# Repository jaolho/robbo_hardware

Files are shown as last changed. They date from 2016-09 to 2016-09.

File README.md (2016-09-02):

# CLONE THE REPOSITORY BY CLICKING THE CLONE BUTTON IN THE UPPER RIGHT SIDE OF THE PAGE - THE ONE WITH A DOWN ARROW. #

# README #

This README would normally document whatever steps are necessary to get your application up and running.

### What is this repository for? ###

* Quick summary
* Version
* [Learn Markdown](https://bitbucket.org/tutorials/markdowndemo)

### How do I get set up? ###

* Summary of set up
* Configuration
* Dependencies
* Database configuration
* How to run tests
* Deployment instructions

### Contribution guidelines ###

* Writing tests
* Code review
* Other guidelines

### Who do I talk to? ###

* Repo owner or admin
* Other community or team contact

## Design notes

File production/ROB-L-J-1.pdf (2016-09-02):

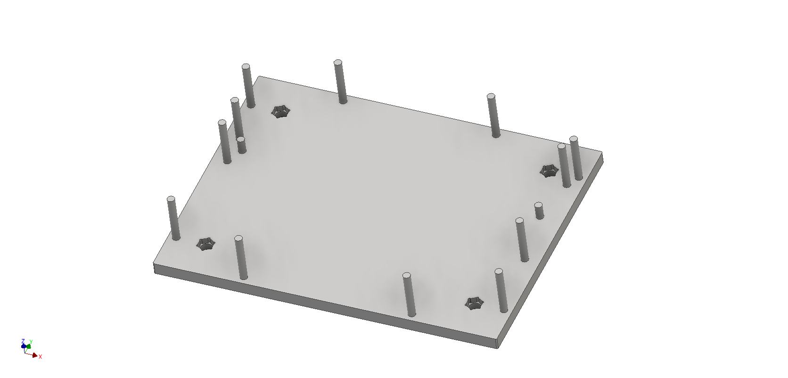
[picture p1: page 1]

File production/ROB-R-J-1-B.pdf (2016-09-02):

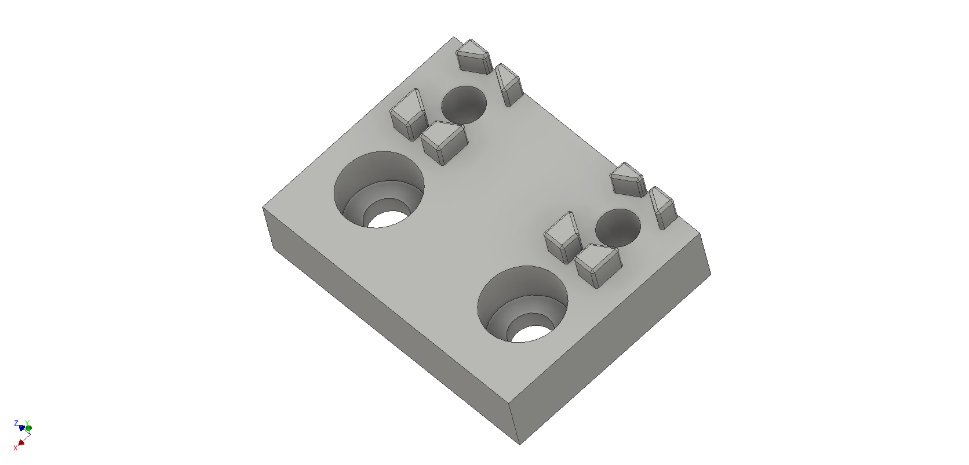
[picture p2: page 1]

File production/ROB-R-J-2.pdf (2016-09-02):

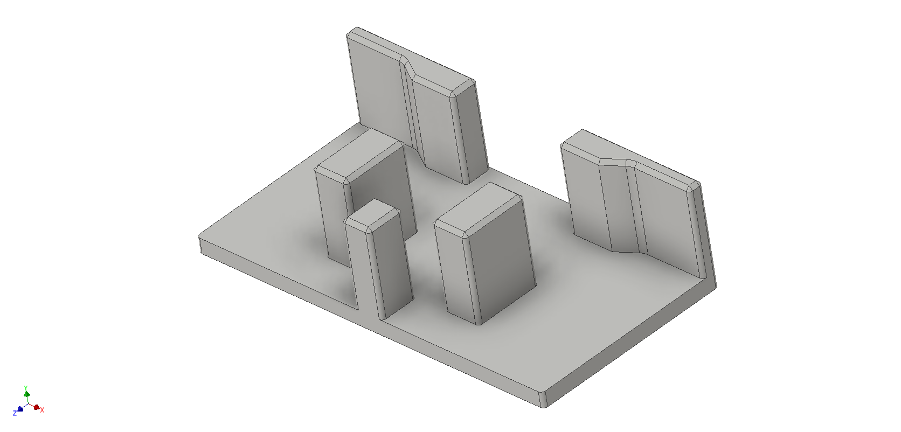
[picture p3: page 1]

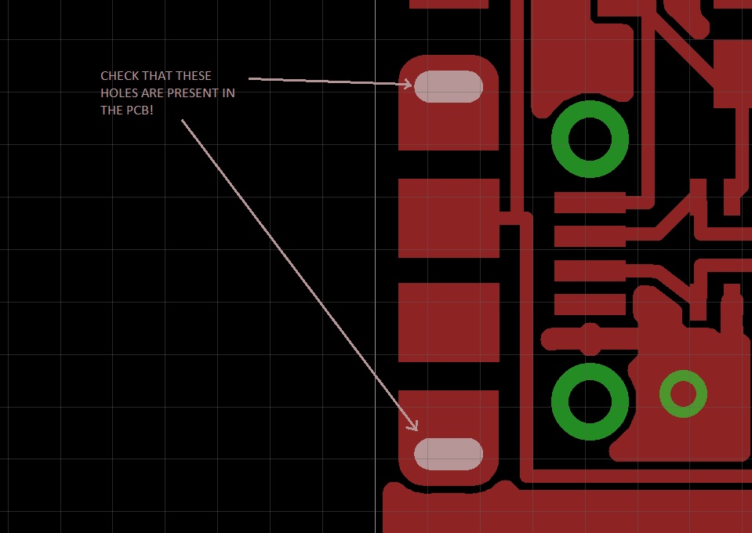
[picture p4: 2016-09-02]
lab/eagle/gerber/USB ADDITIONAL HOLES.jpg

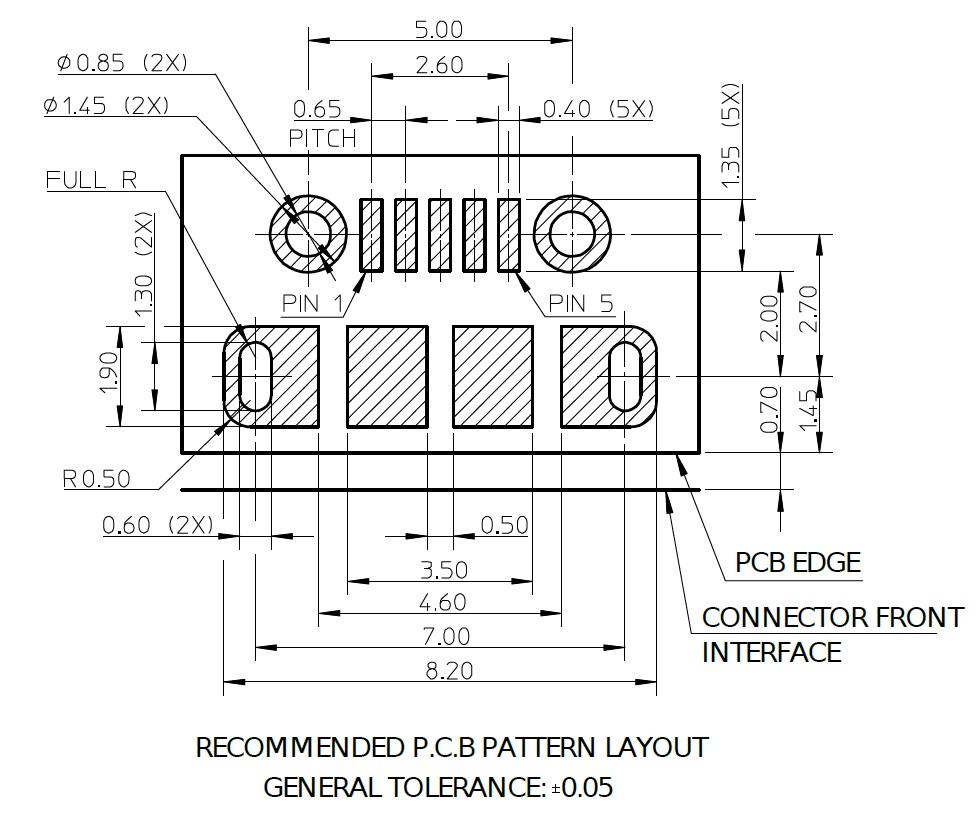
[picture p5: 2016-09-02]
lab/eagle/gerber/USB CONNECTOR HOLE DIMENSIONS.jpg

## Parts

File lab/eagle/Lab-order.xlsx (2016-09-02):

Quantity | Value | Package | Order code | Manufacturer | Manuf. Code | Availability | Price (from) | Description | tot
6 | KSC921J | TACT_SWITCH_4_PIN | 2435155 | C & K COMPONENTS | KSC921J LFS | 807 | 0.288 | C & K COMPONENTS - KSC921J LFS - TACTILE SWITCH, SPST, 0.05A, 32VDC, SMD | 2.2464
1 | 330nF | C0805 | 1833878 | AVX | 08053C334KAT2A | 70485 | 0.131 | AVX - 08053C334KAT2A - CAP, MLCC, X7R, 330NF, 25V, 0805 | 0.1703
10 | 100nF | C0805 | 499687 | AVX | 08055C104KAT2A | 223180 | 0.0086 | AVX - 08055C104KAT2A - CAP, MLCC, X7R, 100NF, 50V, 0805 | 0.1118
1 | 10nF | C0805 | 1759246 | MULTICOMP | MC0805B103K500CT | 109879 | 0.0052 | MULTICOMP - MC0805B103K500CT - CAP, MLCC, X7R, 10NF, 50V, 0805 | 0.00676
2 | 4.7uF | C0805 | 2497057 | WALSIN | 0805X475K250CT | 149027 | 0.0311 | WALSIN - 0805X475K250CT - CAPACITOR, MLCC, X5R, 4.7UF, 25V, 0805 | 0.08086
2 | 22pF | C0805 | 1362555 | YAGEO (PHYCOMP) | CC0805JRNPO9BN220 | 14207 | 0.0038 | YAGEO (PHYCOMP) - CC0805JRNPO9BN220 - CAP, MLCC, C0G/NP0, 22PF, 50V, 0805 | 0.00988
1 | 470nF | C0805 | 1759175 | MULTICOMP | MC0805F474Z250CT | 165234 | 0.0112 | MULTICOMP - MC0805F474Z250CT - CAP, MLCC, Y5V, 470NF, 25V, 0805 | 0.01456
2 | MBR0520 | SOD123 | 1467521 | FAIRCHILD SEMICONDUCTOR | MBR0520L | 9244 | 0.0385 | FAIRCHILD SEMICONDUCTOR - MBR0520L - DIODE, SCHOTTKY, 0.5A, 20V, SMD | 0.1001
4 | 5.1V | SOD-323 | 1431203 | ON SEMICONDUCTOR | MM3Z5V1T1G | 38122 | 0.0196 | ON SEMICONDUCTOR - MM3Z5V1T1G - DIODE, ZENER, 5.1V, 0.2W | 0.10192
1 | 500 mA | PT1206 | 1345942 | TE CONNECTIVITY / RAYCHEM | NANOSMDC050F/13.2-2 | 2740 | 0.123 | TE CONNECTIVITY / RAYCHEM - NANOSMDC050F/13.2-2 - POLYSWITCH, SMD, 1206, 0.5A | 0.1599
1 | FT232RL | SSOP28 | 1146032 | FTDI | FT232RL-REEL | -6 | 1.61 | FTDI - FT232RL-REEL - IC, USB TO UART, SMD, 28SSOP | 2.093
1 | 74HC164D | SO14 | 1085337 | NXP | 74HC164D | 4608 | 0.062 | NXP - 74HC164D - IC, 8BIT SHIFT REGISTER, 14SOIC | 0.0806
1 | ATMEGA328AU/TQFP | TQFP32-08 | 1715486 | ATMEL | ATMEGA328P-AU | 1330 | 1.21 | ATMEL - ATMEGA328P-AU - MCU, 8BIT, ATMEGA, 20MHZ, TQFP-32 | 1.573
1 | 600ohm/100Mhz | R0603 | 1635706 | WURTH ELEKTRONIK | 742792651 | 28900 | 0.0734 | WURTH ELEKTRONIK - 742792651 - FERRITE, BEAD, 0603, 0.2OHM, 1A | 0.09542
3 | KPC-3216SGC (GREEN) | LED3216_PAC | 1318254 | KINGBRIGHT | KPC-3216SGC | 2739 | 0.0877 | KINGBRIGHT - KPC-3216SGC - LED, 1.6MM X 2MM, GREEN, 12MCD, 568NM | 0.34203
1 | KPC-3216YC (YELLOW) | LED3216_PAC | 1318264 | KINGBRIGHT | KPC-3216YC | 210 | 0.0891 | KINGBRIGHT - KPC-3216YC - LED, SMD, CLR LENS, YELLOW | 0.11583
10 | KPC-3216EC (RED) | LED3216_PAC | 1318250 | KINGBRIGHT | KPC-3216EC | 4925 | 0.0862 | KINGBRIGHT - KPC-3216EC - LED, SMD, CLR LENS, RED | 1.1206
1 | ABM-707-RC | ABM-707-RC | 1736563 | PRO SIGNAL | ABM-707-RC | 10790 | 0.494 | PRO SIGNAL - ABM-707-RC - MICROPHONE, OMNI, PCB MOUNT | 0.6422
2 | TSM-108-02-L-SV | FE08 | 1593463 | MULTICOMP | 2212S-08SG-85 | 30147 | 0.126 | MULTICOMP - 2212S-08SG-85 - SOCKET, PCB, 1 ROW, 8WAY | 0.3276
1 | TSM-106-02-L-SV | FE06 | 1593462 | MULTICOMP | 2212S-06SG-85 | 3284 | 0.0914 | MULTICOMP - 2212S-06SG-85 - SOCKET, PCB, 1 ROW, 6WAY | 0.11882
1 | TSM-110-02-L-SV | FE10 | 1593464 | MULTICOMP | 2212S-10SG-85 | 22134 | 0.206 | MULTICOMP - 2212S-10SG-85 - SOCKET, PCB, 1 ROW, 10WAY | 0.2678
1 | SFH3410SMD | SFH3410 | 1226438 | OSRAM | SFH3410-Z | 872 | 0.377 | OSRAM - SFH3410-Z - PHOTOTRANSISTOR, EYE-RESPONSE | 0.4901
1 | LFXTAL003237 | SM49 | 9713808 | IQD FREQUENCY PRODUCTS | LFXTAL003237 | 20932 | 0.135 | IQD FREQUENCY PRODUCTS - LFXTAL003237 - CRYSTAL, SMD, 16MHZ | 0.1755
1 | BC850 | MY_SOT23 | 1081241 | NXP | BC850C,215 | 67732 | 0.0241 | NXP - BC850C,215 - TRANSISTOR, NPN, 45V, SOT-23 | 0.03133
1 | 0R | R0805 | 9333681 | MULTICOMP | MC01W08050R | 906385 | 0.0014 | MULTICOMP - MC01W08050R - RESISTOR, THICK FILM, 0R, 0.1W | 0.00182
23 | 1k | R0805 | 1652936 | VISHAY DRALORIC | CRCW08051K00FKTA | 1325 | 0.018 | VISHAY DRALORIC - CRCW08051K00FKTA - RES, THICK FILM, 1K, 1%, 0.125W, 0805 | 0.5382
9 | 10k | R0805 | 9237755 | YAGEO (PHYCOMP) | RC0805FR-0710KL | 367165 | 0.0042 | YAGEO (PHYCOMP) - RC0805FR-0710KL - RES, THICK FILM, 10K, 1%, 0.125W, 0805 | 0.04914
1 | 2k2 | R0805 | 9237534 | YAGEO (PHYCOMP) | RC0805FR-072K2L. | 16874 | 0.0043 | YAGEO (PHYCOMP) - RC0805FR-072K2L. - RES, THICK FILM, 2K2, 1%, 0.125W, 0805 | 0.00559
2 | 100k | R0805 | 9237879 | YAGEO (PHYCOMP) | RC0805FR-07100KL | 2127 | 0.0043 | YAGEO (PHYCOMP) - RC0805FR-07100KL - RES, THICK FILM, 100K, 1%, 0.125W, 0805 | 0.01118
1 | PTA4543 | PTA4543 | 1688415 | BOURNS | PTA4543-2015DPB103 | 679 | 0.476 | BOURNS - PTA4543-2015DPB103 - POTENTIOMETER, SLIDE, 10K, 45MM | 0.6188
1 | MCABT-458-RC | SMD_SPK_PAC | 2433031 | MULTICOMP | MCABT-458-RC | 248 | 0.892 | MULTICOMP - MCABT-458-RC - SOUNDER, 75DB, 1-25V, SMD | 1.1596
1 | USB-CON-5PIN | USB-MICRO-MOLEX-105017-0001_V2 | 2293836 | MOLEX | 105017-0001 | 5630 | 0.265 | MOLEX - 105017-0001 - MICRO USB, 2.0 TYPE B, RECEPTACLE, SMT | 0.3445
1 | PRTR5V0U4Y | SOT363 | 1757870 | NXP | PRTR5V0U4Y,125 | 14639 | 0.0512 | NXP - PRTR5V0U4Y,125 - DIODE ESD, PROTECT, SOT-363 | 0.06656
1 | UA78M05CDCY | SOT230P700X180-4N | 2296030 | TEXAS INSTRUMENTS | UA78M05CDCY | 2313 | 0.141 | TEXAS INSTRUMENTS - UA78M05CDCY - V REG, 0.5A, 5V, 5%, 4SOT223 | 0.1833
1 | SRF3216A | SRF3216A | 2493828 | BOURNS | SRF3216A-900Y | 969 | 0.31 | BOURNS - SRF3216A-900Y - FILTER, COMMON MODE, 90R, 0.4A, SMD | 0.403
3 | FC68125 | FC68125 | 2309468 | CLIFF ELECTRONIC COMPONENTS | FC68125 | 1011 | 0.49 | CLIFF ELECTRONIC COMPONENTS - FC68125 - CONNECTOR, PHONO, 3.5MM, JACK, 4POLE | 1.911
1 | 200 mA | PT1206 | 1345939 | TE CONNECTIVITY / RAYCHEM | NANOSMDC020F-2 | 439 | 0.1096 | TE CONNECTIVITY / RAYCHEM - NANOSMDC020F-2 - POLYSWITCH, SMD, 1206, 0.2A | 0.14248
2 | 74FST3257 | SO16 | 2464460 | ON SEMICONDUCTOR | 74FST3257DR2G | -2 | 0.166 | ON SEMICONDUCTOR - 74FST3257DR2G - MUX/DEMUX, QUAD, 2:1, SOIC-16 | 0.4316
3 | 220R | M0805 | 2447606 | MULTICOMP | MCWR08X2200FTL | 61112 | 0.0051 | MULTICOMP - MCWR08X2200FTL - RES, THICK FILM, 220R, 1%, 0.125W, 0805 | 0.01989
1 | 219-02 | CTS-219-02 | 1524005 | MULTICOMP | MCEMR-02-T | 43377 | 0.236 | MULTICOMP - MCEMR-02-T - SWITCH, 2 WAY, SPST, FLUSH | 0.3068
 |  |  |  |  |  |  |  |  | 16.66977

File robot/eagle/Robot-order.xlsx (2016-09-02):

Quantity | Value | Package | Order code | Manufacturer | Manuf. Code | Availability | Price (from) | Description
1 | UA78M05CDCY | SOT230P700X180-4N | 2296030 | TEXAS INSTRUMENTS | UA78M05CDCY | 2313 | 0.141 | TEXAS INSTRUMENTS - UA78M05CDCY - V REG, 0.5A, 5V, 5%, 4SOT223
1 | RN42-I/RM | RN42 | 2143310 | MICROCHIP | RN42-I/RM | 4010 | 11.5 | MICROCHIP - RN42-I/RM - MODULE, BLUETOOTH CLASS 2, W/ ANT
3 | KSC921J | TACT_SWITCH_4_PIN | 2435155 | C & K COMPONENTS | KSC921J LFS | 807 | 0.288 | C & K COMPONENTS - KSC921J LFS - TACTILE SWITCH, SPST, 0.05A, 32VDC, SMD
1 | 330nF | C0805 | 1833878 | AVX | 08053C334KAT2A | 70485 | 0.131 | AVX - 08053C334KAT2A - CAP, MLCC, X7R, 330NF, 25V, 0805
18 | 100nF | C0805 | 499687 | AVX | 08055C104KAT2A | 223180 | 0.0086 | AVX - 08055C104KAT2A - CAP, MLCC, X7R, 100NF, 50V, 0805
1 | 10nF | C0805 | 1759246 | MULTICOMP | MC0805B103K500CT | 109879 | 0.0052 | MULTICOMP - MC0805B103K500CT - CAP, MLCC, X7R, 10NF, 50V, 0805
2 | 4.7uF | C0805 | 1735529 | MURATA | GRM21BR61E475KA12L | 12464 | 0.0181 | MURATA - GRM21BR61E475KA12L - CAP, MLCC, X5R, 4.7UF, 25V, 0805
3 | 47uF | C1210 | 1907527 | MURATA | GRM32EC81C476KE15L | 3213 | 0.136 | MURATA - GRM32EC81C476KE15L - CAP, MLCC, X6S, 47UF, 16V, 1210
2 | 22pF | C0805 | 1362555 | YAGEO (PHYCOMP) | CC0805JRNPO9BN220 | 14207 | 0.0038 | YAGEO (PHYCOMP) - CC0805JRNPO9BN220 - CAP, MLCC, C0G/NP0, 22PF, 50V, 0805
2 | MBR0520 | SOD123 | 1467521 | FAIRCHILD SEMICONDUCTOR | MBR0520L | 9259 | 0.0385 | FAIRCHILD SEMICONDUCTOR - MBR0520L - DIODE, SCHOTTKY, 0.5A, 20V, SMD
1 | BAV99 | SOT23 | 1621837 | MULTICOMP | BAV99 | 120250 | 0.0096 | MULTICOMP - BAV99 - DIODE, DUAL, SMALL SIG, 75V, SOT-23-3
1 | 500 mA | PT1206 | 1345942 | TE CONNECTIVITY / RAYCHEM | NANOSMDC050F/13.2-2 | 2740 | 0.123 | TE CONNECTIVITY / RAYCHEM - NANOSMDC050F/13.2-2 - POLYSWITCH, SMD, 1206, 0.5A
1 | FT232RL | SSOP28 | 1146032 | FTDI | FT232RL-REEL | -6 | 1.61 | FTDI - FT232RL-REEL - IC, USB TO UART, SMD, 28SSOP
1 | ATMEGA328AU/TQFP | TQFP32-08 | 1715486 | ATMEL | ATMEGA328P-AU | 1330 | 1.21 | ATMEL - ATMEGA328P-AU - MCU, 8BIT, ATMEGA, 20MHZ, TQFP-32
4 | 1X01 PIN | 1X01 | 2356152 | WURTH ELEKTRONIK | 61300111121 | 155 | 0.0337 | WURTH ELEKTRONIK - 61300111121 - HEADER, 2.54MM, PIN, THT, VERTICAL, 1WAY
1 | 600ohm/100Mhz | R0603 | 1635706 | WURTH ELEKTRONIK | 742792651 | 28900 | 0.0734 | WURTH ELEKTRONIK - 742792651 - FERRITE, BEAD, 0603, 0.2OHM, 1A
3 | KPC-3216SGC | LED3216_PAC | 1318254 | KINGBRIGHT | KPC-3216SGC | 2739 | 0.0877 | KINGBRIGHT - KPC-3216SGC - LED, 1.6MM X 2MM, GREEN, 12MCD, 568NM
2 | APT3216QBC/D (BLUE) | LED3216_PAC | 2217976 | KINGBRIGHT | KP-3216QBC-D | 4477 | 0.115 | KINGBRIGHT - KP-3216QBC-D - LED, SMD, 1206 BLUE
2 | KPC-3216YC | LED3216_PAC | 1318264 | KINGBRIGHT | KPC-3216YC | 210 | 0.0891 | KINGBRIGHT - KPC-3216YC - LED, SMD, CLR LENS, YELLOW
2 | KPC-3216SGC (GREEN) | LED3216_PAC | 1318254 | KINGBRIGHT | KPC-3216SGC | 2739 | 0.0877 | KINGBRIGHT - KPC-3216SGC - LED, 1.6MM X 2MM, GREEN, 12MCD, 568NM
2 | KPC-3216EC (RED) | LED3216_PAC | 1318250 | KINGBRIGHT | KPC-3216EC | 4925 | 0.0862 | KINGBRIGHT - KPC-3216EC - LED, SMD, CLR LENS, RED
1 | LV8548 | LV8548 | 2217011 | ON SEMICONDUCTOR | LV8548MC-AH | 949 | 0.639 | ON SEMICONDUCTOR - LV8548MC-AH - DRIVER, MOTOR, 2CH, 12V, BIDIR, 10SOIC
1 | 16MHz | SM49 | 9713808 | IQD FREQUENCY PRODUCTS | LFXTAL003237 | 20942 | 0.135 | IQD FREQUENCY PRODUCTS - LFXTAL003237 - CRYSTAL, SMD, 16MHZ
1 | 0R | R0805 | 9333681 | MULTICOMP | MC01W08050R | 906385 | 0.0014 | MULTICOMP - MC01W08050R - RESISTOR, THICK FILM, 0R, 0.1W
16 | 1k | R0805 | 1652936 | VISHAY DRALORIC | CRCW08051K00FKTA | 1325 | 0.018 | VISHAY DRALORIC - CRCW08051K00FKTA - RES, THICK FILM, 1K, 1%, 0.125W, 0805
8 | 10k | R0805 | 9237755 | YAGEO (PHYCOMP) | RC0805FR-0710KL | 377165 | 0.0042 | YAGEO (PHYCOMP) - RC0805FR-0710KL - RES, THICK FILM, 10K, 1%, 0.125W, 0805
1 | 22k | R0805 | 1099809 | WELWYN | WCR0805-22KFI | 53934 | 0.0059 | WELWYN - WCR0805-22KFI - RES, THICK FILM, 22K, 1%, 0.125W, 0805
1 | 39k | R0805 | 1100325 | WELWYN | WCR0805-39KFI | 32215 | 0.0063 | WELWYN - WCR0805-39KFI - RES, THICK FILM, 39K, 1%, 0.1W, 0805
1 | PRTR5V0U4Y | SOT363 | 1757870 | NXP | PRTR5V0U4Y,125 | 14639 | 0.0512 | NXP - PRTR5V0U4Y,125 - DIODE ESD, PROTECT, SOT-363
1 | USB-CON-5PIN | USB-MICRO-MOLEX-105017-0001_V2 | 2293836 | MOLEX | 105017-0001 | 5630 | 0.265 | MOLEX - 105017-0001 - MICRO USB, 2.0 TYPE B, RECEPTACLE, SMT
1 | SRF3216A | SRF3216A | 2493828 | BOURNS | SRF3216A-900Y | 969 | 0.31 | BOURNS - SRF3216A-900Y - FILTER, COMMON MODE, 90R, 0.4A, SMD
2 | KTIR07SMD | KTIR07 | 2079967 | KINGBRIGHT | KTIR0721DS | -6 | 0.221 | KINGBRIGHT - KTIR0721DS - PHOTO INTERRUPTER
1 | SN74HCT14PWR | SOP65P640X120-14N | 1287559 | TEXAS INSTRUMENTS | SN74HCT14PWR | 1990 | 0.0782 | TEXAS INSTRUMENTS - SN74HCT14PWR - IC, INVERTER, SMD, TSSOP14, 7V
1 | CD4072BM | SOIC127P600X175-14N | 1753434 | TEXAS INSTRUMENTS | CD4072BM | 150 | 0.0954 | TEXAS INSTRUMENTS - CD4072BM - LOGIC, DUAL 4INPUT OR GATE, 14SOIC
2 | TC33-TRIMPOT | TC33-TRIMPOT | 1689867 | BOURNS | TC33X-2-503E | 1603 | 0.0709 | BOURNS - TC33X-2-503E - TRIMMER, POT, 50K, 25%, 1TURN, SMD
1 | N-MOSFET | SOT23 | 9845011 | FAIRCHILD SEMICONDUCTOR | FDV301N | 16626 | 0.0258 | FAIRCHILD SEMICONDUCTOR - FDV301N - N CHANNEL MOSFET, 220MA, 25V, SOT23
15 | 220R | R0805 | 2447606 | MULTICOMP | MCWR08X2200FTL | 61112 | 0.0051 | MULTICOMP - MCWR08X2200FTL - RES, THICK FILM, 220R, 1%, 0.125W, 0805
2 | 750k | R0805 | 9333550 | MULTICOMP | MC01W08051750K | 1679 | 0.0032 | MULTICOMP - MC01W08051750K - RES, THICK FILM, 750K, 1%, 0.1W, 0805
1 | 330k | R0805 | 1652983 | VISHAY DRALORIC | CRCW0805330KFKEA | 5406 | 0.008 | VISHAY DRALORIC - CRCW0805330KFKEA - RES, THICK FILM, 330K, 1%, 0.125W, 0805
1 | 4M7 | R0805 | 2352630 | VISHAY DRALORIC | RCV08054M70FKEA | 655 | 0.0155 | VISHAY DRALORIC - RCV08054M70FKEA - RES, THICK FILM, 4M7, 1%, 0.125W, 0805
1 | 4060BM | SO16 | 1741260 | TEXAS INSTRUMENTS | CD4060BM | 3715 | 0.0976 | TEXAS INSTRUMENTS - CD4060BM - LOGIC, BIN COUNTER/DIV/OSC, 16SOIC
1 | UA78M33CDCY | SOT230P700X180-4N | 2296031 | TEXAS INSTRUMENTS | UA78M33CDCY | 1846 | 0.125 | TEXAS INSTRUMENTS - UA78M33CDCY - V REG, 2VDO, 0.5A, 3.3V, 4SOT223
1 | BATTERY_9V | BATTERY_PAC | 1888429 | KEYSTONE | 967 | -10 | 0.472 | KEYSTONE - 967 - BATTERY CONTACT, 9V, VERTICAL PCB SNAP-ON
2 | 1uF | C0805 | 2496944 | WALSIN | 0805B104K500CT | 2004666 | 0.0041 | WALSIN - 0805B104K500CT - CAPACITOR, MLCC, X7R, 0.1UF, 50V, 0805
1 | LTC2955CTS8-2 | 8TSOT23 | 2097940 | LINEAR TECHNOLOGY | LTC2955CTS8-2#TRMPBF | 521 | 1.67 | LINEAR TECHNOLOGY - LTC2955CTS8-2#TRMPBF - CONTROLLER, PUSHBUTTON ON/OFF, 8TSOT23
4 | SD1206 | SD1206 | 2400198 | AVX | SD1206S040S2R0 | 2356 | 0.0816 | AVX - SD1206S040S2R0 - DIODE, SCHOTTKY, 2A, 40V, SOD-123
2 | 200 mA | PT1206 | 1345939 | TE CONNECTIVITY / RAYCHEM | NANOSMDC020F-2 | 439 | 0.1096 | TE CONNECTIVITY / RAYCHEM - NANOSMDC020F-2 - POLYSWITCH, SMD, 1206, 0.2A
1 | 2x11 HEADER | 2X11 | 1593495 | MULTICOMP | 2214S-22SG-85 | 1244 | 0.273 | MULTICOMP - 2214S-22SG-85 - SOCKET, PCB, 2 ROW, VERT, 22WAY
2 | IRLML5203PBF (3A) | SOT23 | 9103511 | INTERNATIONAL RECTIFIER | IRLML5203PBF | 32283 | 0.0765 | INTERNATIONAL RECTIFIER - IRLML5203PBF - MOSFET,P CH,-30V,-3A,SOT23
1 | 90k9 | R0805 | 2141897 | MULTICOMP | MC01W0805190K9 | 2455 | 0.0044 | MULTICOMP - MC01W0805190K9 - RES, THICK FILM, 90K9, 1%, 0.1W, 0805
4 | 100k | R0805 | 9237879 | YAGEO (PHYCOMP) | RC0805FR-07100KL | 2127 | 0.0043 | YAGEO (PHYCOMP) - RC0805FR-07100KL - RES, THICK FILM, 100K, 1%, 0.125W, 0805
1 | 120k | R0805 | 9237887 | YAGEO (PHYCOMP) | RC0805FR-07120KL | 8001 | 0.0018 | YAGEO (PHYCOMP) - RC0805FR-07120KL - RES, THICK FILM, 120K, 1%, 0.125W, 0805
1 | 1M | R0805 | 1853267 | VISHAY DALE | CRCW08051M00FKTB | 3248 | 0.006 | VISHAY DALE - CRCW08051M00FKTB - RES, THICK FILM, 1M, 1%, 0.125W, 0805
3 | MAX803SC | SC70-3L | 2318552 | ON SEMICONDUCTOR | MAX803SQ293T1G | 2885 | 0.108 | ON SEMICONDUCTOR - MAX803SQ293T1G - RESET, 2.93VTH, 0.14-0.46S, ACT LW,3SC70
1 | SWS006 | SMS-006 | 9472045 | MULTICOMP | MCDM(R)-06-T | 5005 | 1.13 | MULTICOMP - MCDM(R)-06-T - SWITCH, DIL, SMD, 6WAY
5 | ESDA5V3L | SOT23 | 1749266 | STMICROELECTRONICS | ESDA5V3L | 6822 | 0.0705 | STMICROELECTRONICS - ESDA5V3L - TRANSIL ARRAY UNI DUAL ESD SOT-23

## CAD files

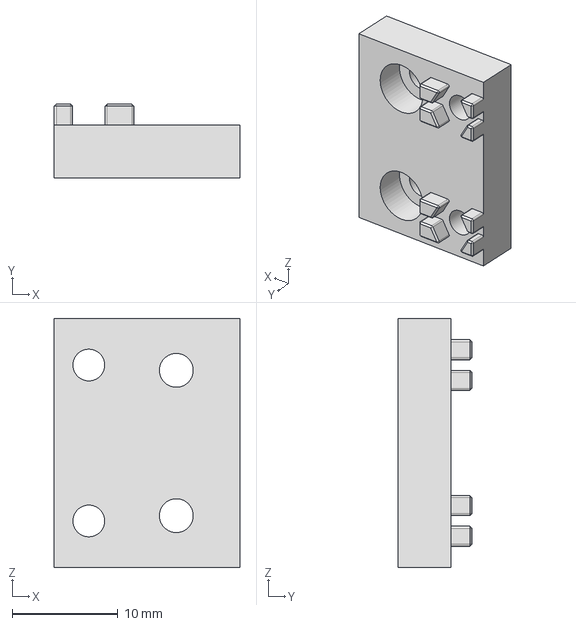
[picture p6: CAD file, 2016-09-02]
production/ROB-R-J-1.stp
17.5 x 7.00 x 23.5 mm

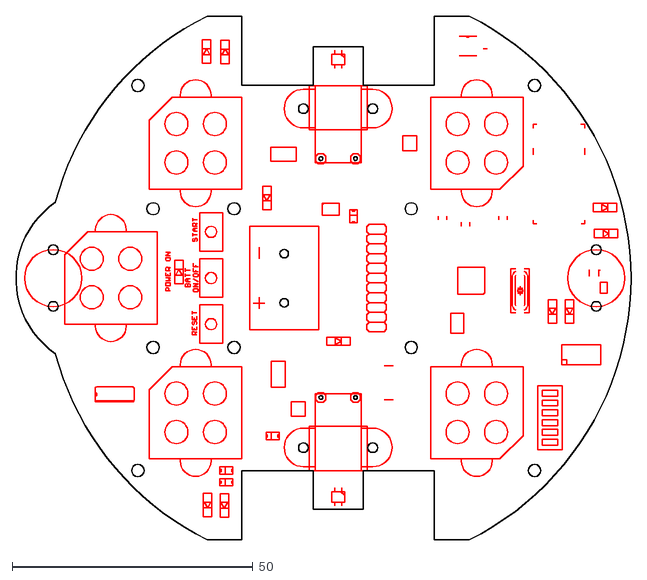
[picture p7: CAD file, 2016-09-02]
robot/plastics/Robot reference.dxf
127.7 x 108.7

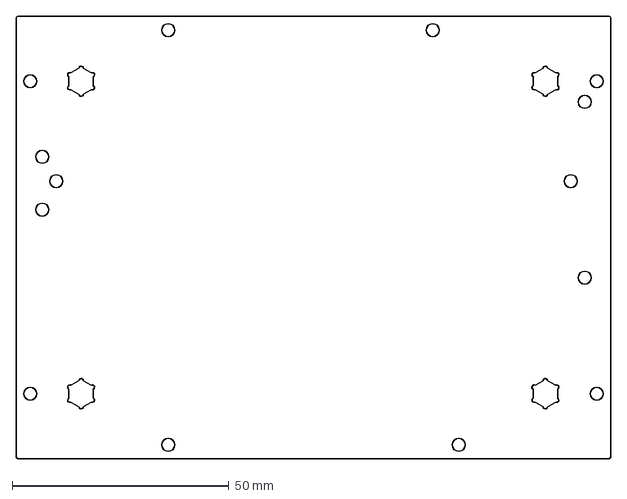
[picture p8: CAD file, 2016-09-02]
production/ROB-L-J-1-FACE1.dxf
137.0 x 102.0 mm

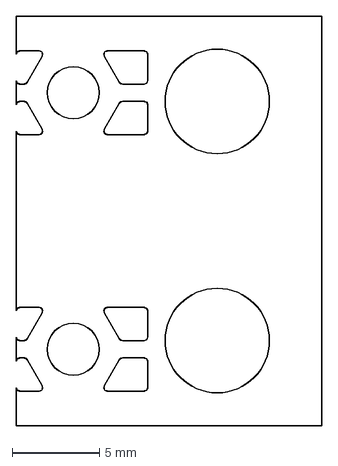
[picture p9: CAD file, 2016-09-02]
production/ROB-R-J-1-B-FACE1.dxf
17.5 x 23.5 mm

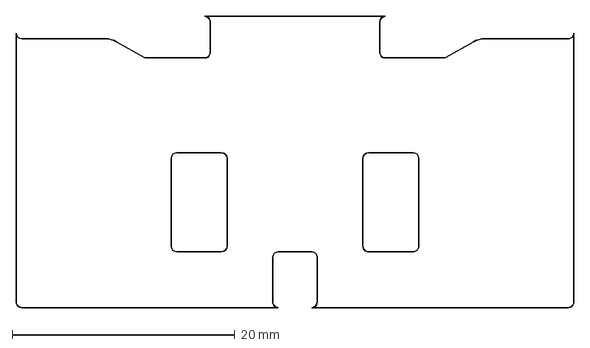
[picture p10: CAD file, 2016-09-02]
production/ROB-R-J-2-FACE1.dxf
50.0 x 26.1 mm

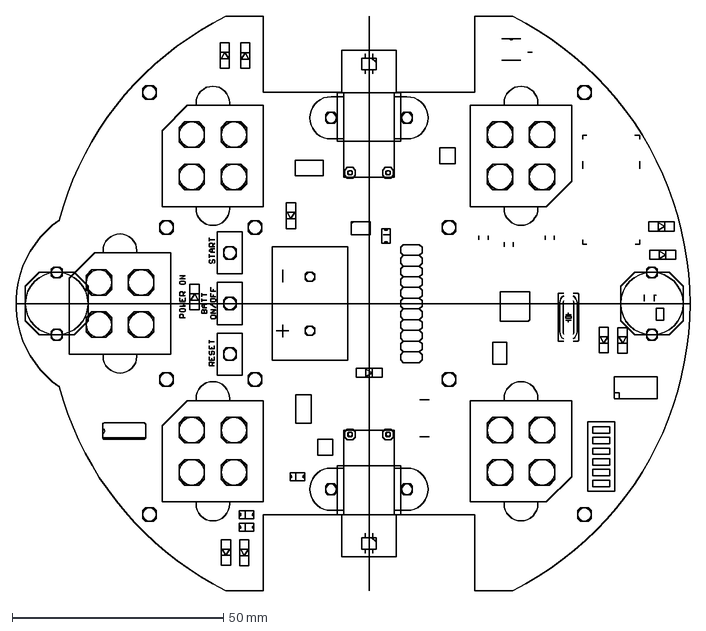
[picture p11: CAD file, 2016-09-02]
production/ROB-R-FACE1.dxf
159.7 x 136.0 mm

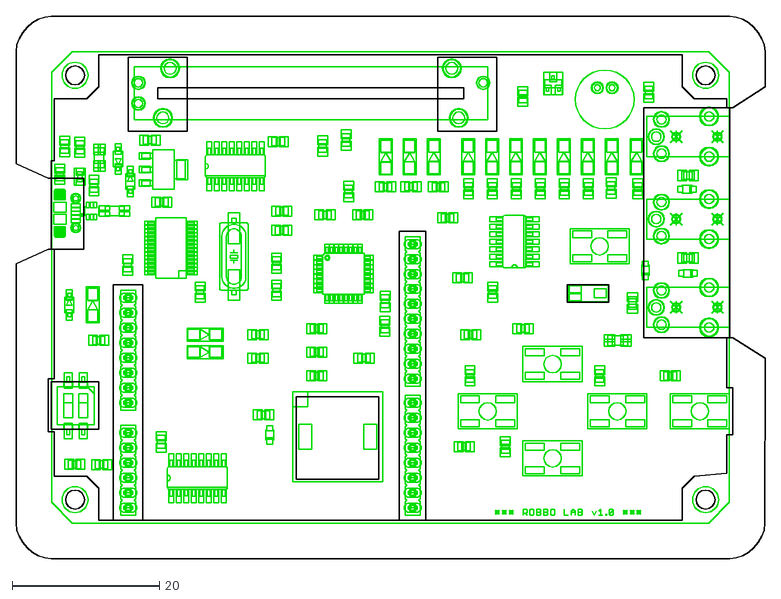
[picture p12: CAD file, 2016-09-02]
production/Lab-plastics.dxf
101.6 x 73.6

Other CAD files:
production/OldVersions/ROB-L-J-1-B.0001.ipt
production/OldVersions/ROB-L-J-1-B.0002.ipt
production/OldVersions/ROB-L-J-1.0002.ipt
production/OldVersions/ROB-L-J-1.0004.ipt
production/OldVersions/ROB-R-J-1.0004.ipt
production/OldVersions/ROB-R-J-2.0003.ipt
production/ROB-L-J-1.ipt
production/ROB-R-J-1-B.ipt
production/ROB-R-J-1.dwg
production/ROB-R-J-1.ipt
production/ROB-R-J-2.ipt
production/ROB-R-J-3.ipt

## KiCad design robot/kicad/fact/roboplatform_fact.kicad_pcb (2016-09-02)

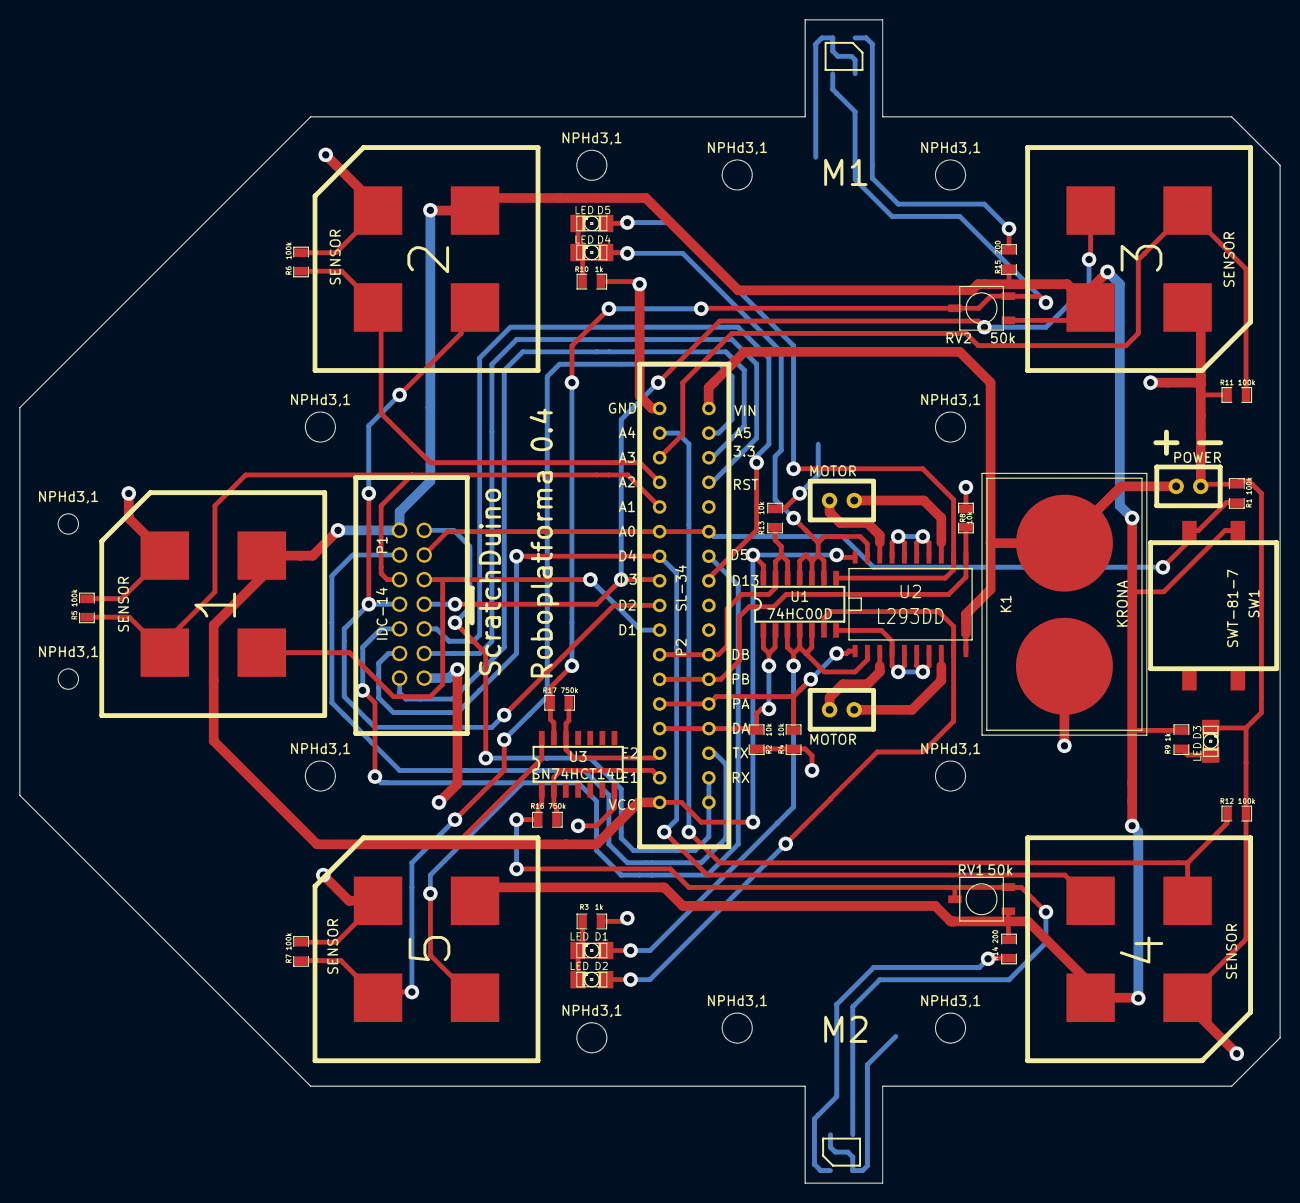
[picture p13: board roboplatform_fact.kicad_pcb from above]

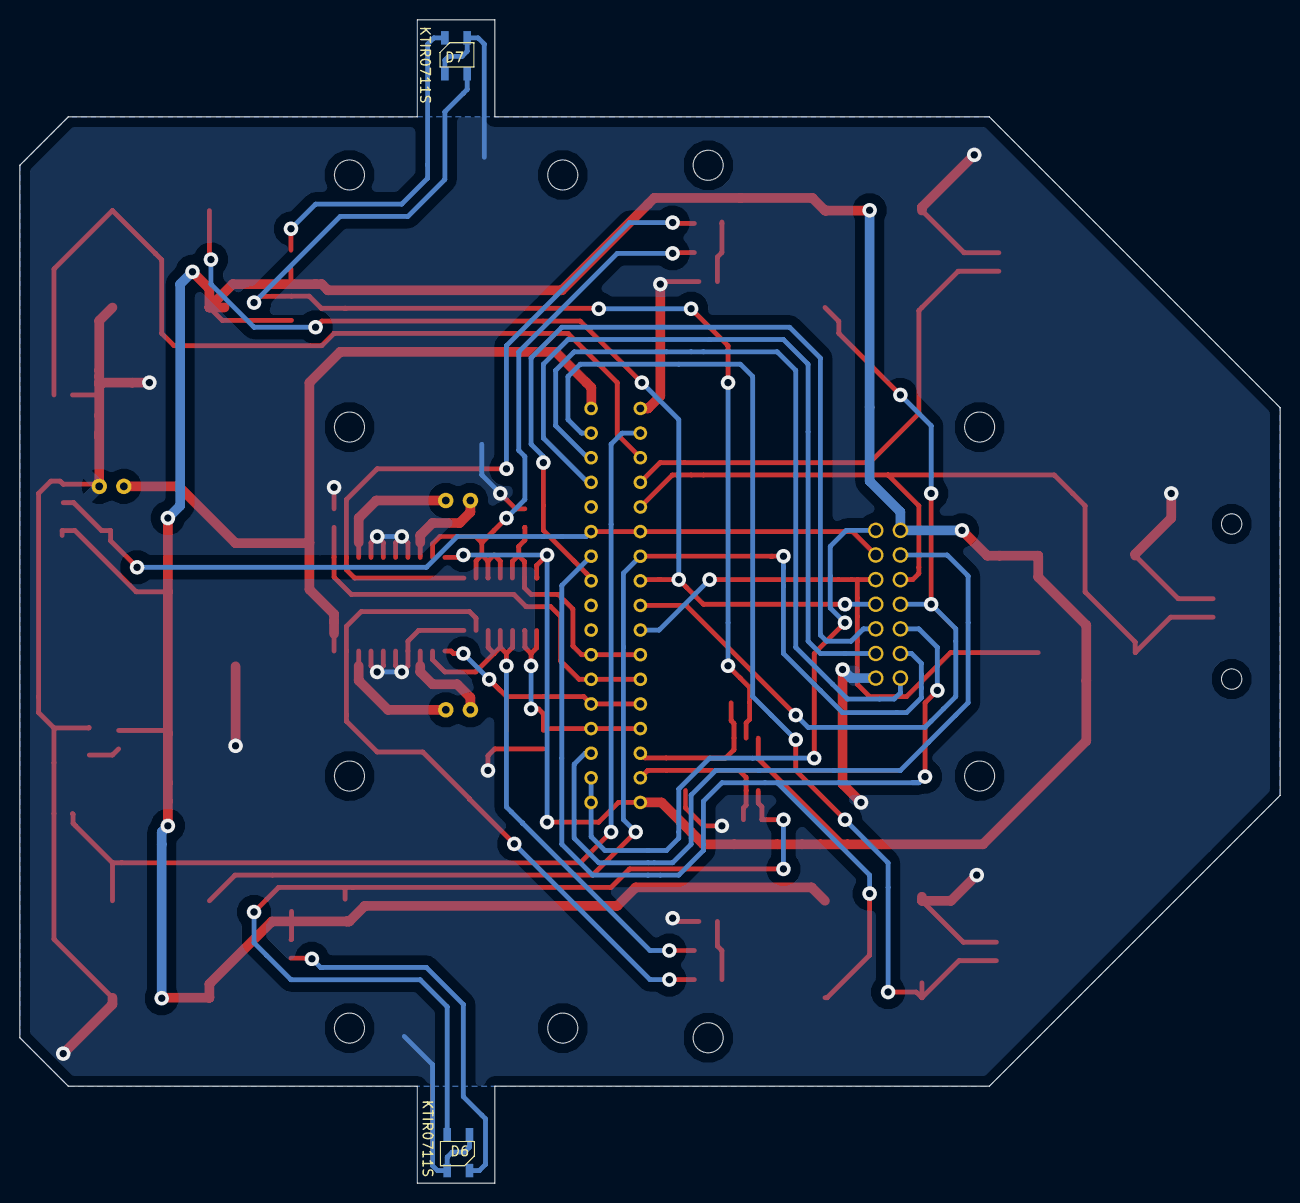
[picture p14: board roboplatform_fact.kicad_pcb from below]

Board: 2 copper layers, 130.0 x 120.0 mm, 53 parts (2 on the bottom side), 40 nets.

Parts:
D1, D2, D3, D4, D5: LED; LED-1206
D6, D7: KTIR0711S
K1: KRONA
NPHd3,1, NPHd3,1#2, NPHd3,1#3, NPHd3,1#4, NPHd3,1#5, NPHd3,1#6, NPHd3,1#7, NPHd3,1#8, NPHd3,1#9, NPHd3,1#10: NPHd3,1
NPHd3,1#11, NPHd3,1#12: NPHd2,1
P1: IDC-14; IDC-14M_SOCKET
P2: SL-34; SL-34_SOCKET
P3, P12: MOTOR
P6, P7, P8, P10, P11: SENSOR; SENSOR_SOCKET
P9: POWER
R1, R5, R6, R7, R11, R12: 100k; SMD0805
R2, R4, R8, R13: 10k; SMD0805
R3, R9, R10: 1k; SMD0805
R14, R15: 200; SMD0805
R16, R17: 750k; SMD0805
RV1, RV2: 50k; 3314G-1-503E
SW1: SWT-81-7
U1: 74HC00D; SOIC-14
U2: L293DD; SO20
U3: SN74HCT14D; SOIC-14

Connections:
A1: P1.10, P2.5, P6.4, R5.1
A2: P2.4, P7.4, R6.1
A3: P2.3, P10.4, R11.1
A4: P2.2, P11.4, R12.1
A5: P2.33, P8.4, R7.1
D1: P1.9, P2.10, P6.3
D2: P1.8, P2.9, P7.3
D3: P1.7, P2.8, P10.3
D4: P1.4, P2.7, P11.3
D5: P1.6, P2.28, P8.3
DIR_A: P2.14, P2.21, R2.1, U1.1, U1.2
DIR_B: P2.11, P2.24, R13.1, U1.12, U1.13
ENC1: P2.16, R16.1, U3.2
ENC2: P2.15, R17.2, U3.12
GND: D3.2, D6.2, D6.4, D7.2, D7.4, K1.2, P1.1, P2.1, P6.1, P7.1, P8.1, P9.2, P10.1, P11.1, R1.2, R2.2, R3.1, R4.1, R5.2, R6.2, R7.2, R8.2, R10.1, R11.2, R12.2, R13.2, U1.7, U2.4, U2.5, U2.6, U2.7, U2.14, U2.15, U2.16, U2.17, U3.7
unnamed: P1.12, P2.20
unnamed: P1.13, P2.18, P2.19
unnamed: P1.3, P2.31
unnamed: P1.2, P2.32
unnamed: P3.2, U2.3
unnamed: P1.11, P2.6, P2.29, R1.1, SW1.1
unnamed: P3.1, U2.8
unnamed: D1.1, U1.3, U1.4, U1.5, U2.2
unnamed: P12.1, U2.13
unnamed: P12.2, U2.18
unnamed: D4.1, U1.9, U1.10, U1.11, U2.19
unnamed: D7.1, R15.2
unnamed: D6.1, R14.2
unnamed: D2.1, U1.6, U2.9
unnamed: P1.5, P2.27
unnamed: D3.1, R9.2
unnamed: D7.3, R17.1, RV2.1, RV2.2, U3.13
unnamed: D6.3, R16.2, RV1.1, RV1.2, U3.1
unnamed: D1.2, D2.2, R3.2
unnamed: D4.2, D5.2, R10.2
unnamed: D5.1, U1.8, U2.12
PWM_A: P2.13, P2.22, R4.2, U2.1
PWM_B: P2.12, P2.23, R8.1, U2.11
VCC: P1.14, P2.17, P6.2, P7.2, P8.2, P10.2, P11.2, R9.1, R14.1, R15.1, RV1.3, RV2.3, SW1.2, U1.14, U2.20, U3.14
V_IN: K1.1, P2.34, P9.1, U2.10

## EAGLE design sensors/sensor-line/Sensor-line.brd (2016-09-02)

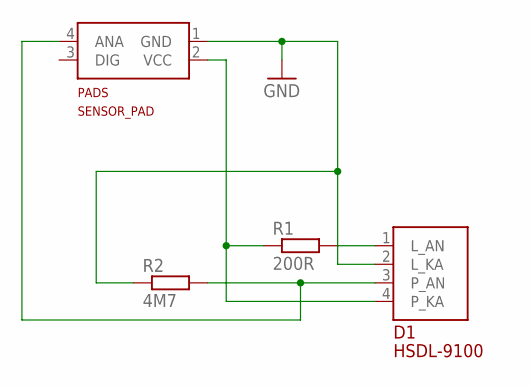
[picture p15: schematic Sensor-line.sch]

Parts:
D1: HSDL-9100; MPN HSDL-9100-021
PADS: SENSOR_PAD
R1: 200R; R1206; MPN ERJ8ENF2000V
R2: 4M7; R0805; MPN ASC0805-4M7FT5

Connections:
GND: D1.2 (L_KA), PADS.1 (GND), R2.1
unnamed: D1.1 (L_AN), R1.2
unnamed: D1.3 (P_AN), PADS.4 (ANA), R2.2
unnamed: D1.4 (P_KA), PADS.2 (VCC), R1.1

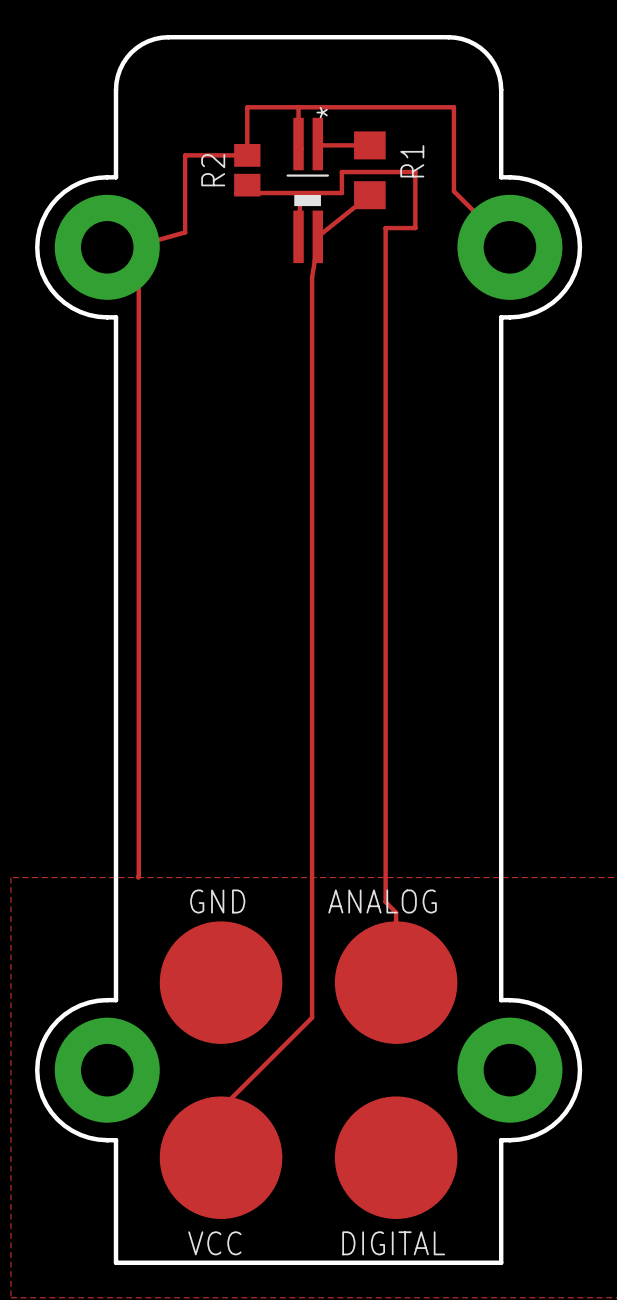
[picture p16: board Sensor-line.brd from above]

Board: 2 copper layers, 31.0 x 70.0 mm, 4 parts (1 on the bottom side), 4 nets.

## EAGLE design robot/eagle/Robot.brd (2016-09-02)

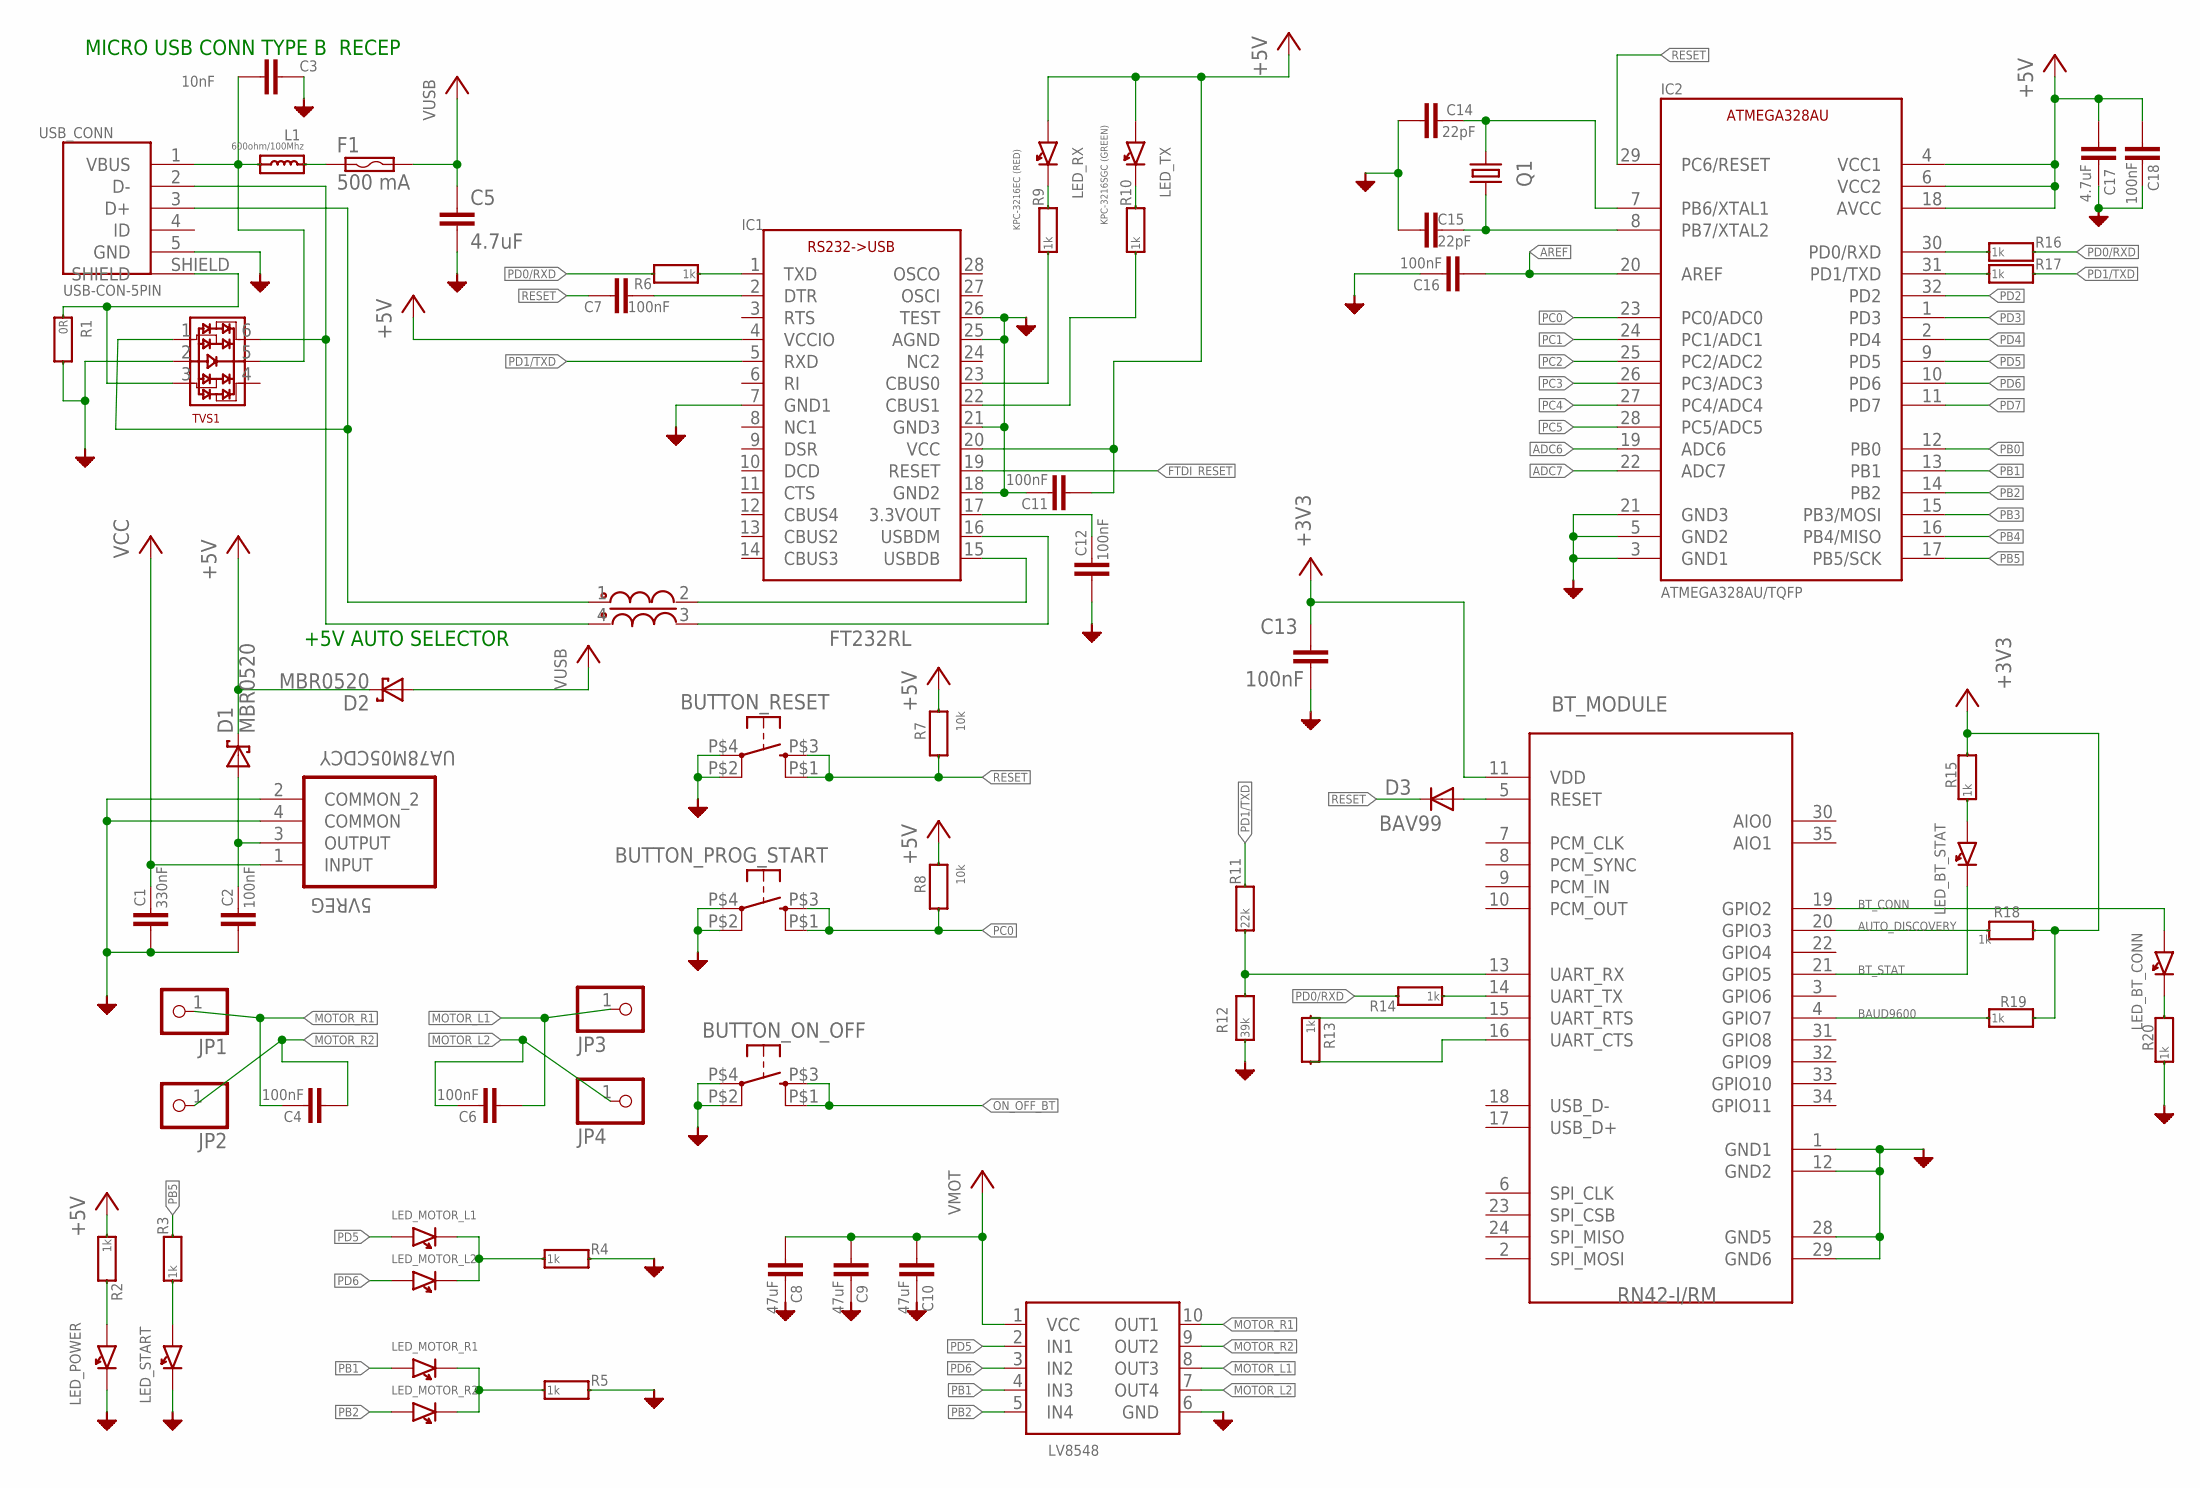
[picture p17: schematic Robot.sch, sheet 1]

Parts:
5VREG: UA78M05CDCY; SOT230P700X180-4N
BT_MODULE: RN42-I/RM; RN42; MPN RN42-I/RM
BUTTON_ON_OFF: KSC921J; TACT_SWITCH_4_PIN; MPN KSC921J LFS
BUTTON_PROG_START: KSC921J; TACT_SWITCH_4_PIN; MPN KSC921J LFS
BUTTON_RESET: KSC921J; TACT_SWITCH_4_PIN; MPN KSC921J LFS
C1: 330nF; C0805; MPN 08053C334KAT2A
C2, C4, C6, C7, C11, C12, C13, C16, C18: 100nF; C0805; MPN 08055C104KAT2A
C3: 10nF; C0805; MPN MC0805B103K500CT
C5, C17: 4.7uF; C0805; MPN GRM21BR61E475KA12L
C8, C9, C10: 47uF; C1210; MPN GRM32EC81C476KE15L
C14, C15: 22pF; C0805; MPN CC0805JRNPO9BN220
D1, D2: MBR0520; SOD123; MPN MBR0520L
D3: BAV99; SOT23; MPN BAV99
F1: 500 mA; PT1206; MPN NANOSMDC050F/13.2-2
IC1: FT232RL; SSOP28; MPN FT232RL-REEL
IC2: ATMEGA328AU/TQFP; TQFP32-08; MPN ATMEGA328P-AU
JP1, JP2, JP3, JP4: 1X01 PIN; 1X01; MPN 61300111121
L1: 600ohm/100Mhz; R0603; MPN 742792651
LED_BT_CONN: KPC-3216SGC; LED3216_PAC; MPN KPC-3216SGC
LED_BT_STAT: KPC-3216SGC; LED3216_PAC; MPN KPC-3216SGC
LED_MOTOR_L1: APT3216QBC/D (BLUE); LED3216_PAC; MOUSER_PART_NO 604-APT3216QBC/D
LED_MOTOR_L2: KPC-3216YC; LED3216_PAC; MPN KPC-3216YC
LED_MOTOR_R1: APT3216QBC/D (BLUE); LED3216_PAC; MOUSER_PART_NO 604-APT3216QBC/D
LED_MOTOR_R2: KPC-3216YC; LED3216_PAC; MPN KPC-3216YC
LED_POWER: KPC-3216SGC (GREEN); LED3216_PAC; MPN KPC-3216SGC
LED_RX: KPC-3216EC (RED); LED3216_PAC; MPN KPC-3216EC
LED_START: KPC-3216SGC; LED3216_PAC; MPN KPC-3216SGC
LED_TX: KPC-3216SGC (GREEN); LED3216_PAC; MPN KPC-3216SGC
MOTOR_CONTROLLER: LV8548; MPN LV8548MC-AH
Q1: 16MHz; SM49; MPN LFXTAL003237
R1: 0R; R0805; MPN MC01W08050R
R2, R3, R4, R5, R6, R9, R10, R13, R14, R15, R16, R17, R18, R19, R20: 1k; R0805; MPN CRCW08051K00FKTA
R7, R8: 10k; R0805; MPN RC0805FR-0710KL
R11: 22k; R0805; MPN WCR0805-22KFI
R12: 39k; R0805; MPN WCR0805-39KFI
TVS1: PRTR5V0U4Y; SOT363; MPN PRTR5V0U4Y,125
USB_CONN: USB-CON-5PIN; USB-MICRO-MOLEX-105017-0001_V2; MPN 105017-0001
USB_FILTER: SRF3216A; MPN SRF3216A-900Y

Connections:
+3V3: BT_MODULE.11 (VDD), C13.1, R15.2, R18.2, R19.2; also elsewhere on the board
+5V: C11.2, C17.2, C18.2, D1.1 (K), D2.1 (K), IC1.4 (VCCIO), IC1.20 (VCC), IC2.4 (VCC1), IC2.6 (VCC2), IC2.18 (AVCC), LED_RX.1, LED_TX.1, R2.1, R7.2, R8.2; also elsewhere on the board
ADC6: IC2.19 (ADC6); also elsewhere on the board
ADC7: IC2.22 (ADC7); also elsewhere on the board
AREF: C16.2, IC2.20 (AREF); also elsewhere on the board
AUTO_DISCOVERY: BT_MODULE.20 (GPIO3), R18.1
BAUD9600: BT_MODULE.4 (GPIO7), R19.1
BT_CONN: BT_MODULE.19 (GPIO2), LED_BT_CONN.1
BT_STAT: BT_MODULE.21 (GPIO5), LED_BT_STAT.2
FTDI_RESET: IC1.19 (RESET); also elsewhere on the board
GND: 5VREG.2 (COMMON_2), 5VREG.4 (COMMON), BT_MODULE.1 (GND1), BT_MODULE.12 (GND2), BT_MODULE.28 (GND5), BT_MODULE.29 (GND6), BUTTON_ON_OFF.P$2 (2), BUTTON_ON_OFF.P$4 (1), BUTTON_PROG_START.P$2 (2), BUTTON_PROG_START.P$4 (1), BUTTON_RESET.P$2 (2), BUTTON_RESET.P$4 (1), C1.2, C2.2, C3.1, C5.2, C8.1, C9.1, C10.1, C11.1, C12.2, C13.2, C14.2, C15.2, C16.1, C17.1, C18.1, IC1.7 (GND1), IC1.18 (GND2), IC1.21 (GND3), IC1.25 (AGND), IC1.26 (TEST), IC2.3 (GND1), IC2.5 (GND2), IC2.21 (GND3), LED_POWER.2, LED_START.2, MOTOR_CONTROLLER.6 (GND), R1.2, R4.2, R5.2, R12.1, R20.1, TVS1.2, USB_CONN.5 (GND); also elsewhere on the board
MOTOR_L1: C6.2, JP3.1, MOTOR_CONTROLLER.8 (OUT3)
MOTOR_L2: C6.1, JP4.1, MOTOR_CONTROLLER.7 (OUT4)
MOTOR_L_ON: LED_MOTOR_L1.2, LED_MOTOR_L2.2, R4.1
MOTOR_R1: C4.1, JP1.1, MOTOR_CONTROLLER.10 (OUT1)
MOTOR_R2: C4.2, JP2.1, MOTOR_CONTROLLER.9 (OUT2)
MOTOR_R_ON: LED_MOTOR_R1.2, LED_MOTOR_R2.2, R5.1
unnamed: BT_MODULE.5 (RESET), D3.1 (A)
unnamed: IC1.1 (TXD), R6.1
unnamed: LED_START.1, R3.1
unnamed: BT_MODULE.14 (UART_TX), R14.1
unnamed: BT_MODULE.15 (UART_RTS), R13.1
unnamed: BT_MODULE.16 (UART_CTS), R13.2
unnamed: IC1.15 (USBDB), USB_FILTER.2
unnamed: LED_BT_STAT.1, R15.1
unnamed: LED_BT_CONN.2, R20.2
unnamed: IC1.16 (USBDM), USB_FILTER.3
unnamed: BT_MODULE.13 (UART_RX), R11.1, R12.2
unnamed: F1.1A (1), F1.1B (1), L1.1
unnamed: 5VREG.3 (OUTPUT), C2.1, D1.2 (A)
unnamed: C12.1, IC1.17 (3.3VOUT)
unnamed: C15.1, IC2.8 (PB7/XTAL2), Q1.2
unnamed: C14.1, IC2.7 (PB6/XTAL1), Q1.1
unnamed: TVS1.1, USB_CONN.3 (D+), USB_FILTER.1
unnamed: TVS1.6, USB_CONN.2 (D-), USB_FILTER.4
unnamed: C7.1, IC1.2 (DTR)
unnamed: C3.2, L1.2, TVS1.5, USB_CONN.1 (VBUS)
unnamed: IC1.23 (CBUS0), R9.1
unnamed: LED_RX.2, R9.2
unnamed: LED_TX.2, R10.2
unnamed: IC1.22 (CBUS1), R10.1
unnamed: LED_POWER.1, R2.2
unnamed: IC2.30 (PD0/RXD), R16.1
unnamed: IC2.31 (PD1/TXD), R17.1
ON_OFF_BT: BUTTON_ON_OFF.P$1 (4), BUTTON_ON_OFF.P$3 (3); also elsewhere on the board
PB0: IC2.12 (PB0); also elsewhere on the board
PB1: IC2.13 (PB1), LED_MOTOR_R1.1, MOTOR_CONTROLLER.4 (IN3); also elsewhere on the board
PB2: IC2.14 (PB2), LED_MOTOR_R2.1, MOTOR_CONTROLLER.5 (IN4)
PB3: IC2.15 (PB3/MOSI); also elsewhere on the board
PB4: IC2.16 (PB4/MISO); also elsewhere on the board
PB5: IC2.17 (PB5/SCK), R3.2; also elsewhere on the board
PC0: BUTTON_PROG_START.P$1 (4), BUTTON_PROG_START.P$3 (3), IC2.23 (PC0/ADC0), R8.1; also elsewhere on the board
PC1: IC2.24 (PC1/ADC1); also elsewhere on the board
PC2: IC2.25 (PC2/ADC2); also elsewhere on the board
PC3: IC2.26 (PC3/ADC3); also elsewhere on the board
PC4: IC2.27 (PC4/ADC4); also elsewhere on the board
PC5: IC2.28 (PC5/ADC5); also elsewhere on the board
PD0/RXD: R6.2, R14.2, R16.2
PD1/TXD: IC1.5 (RXD), R11.2, R17.2
PD2: IC2.32 (PD2); also elsewhere on the board
PD3: IC2.1 (PD3); also elsewhere on the board
PD4: IC2.2 (PD4); also elsewhere on the board
PD5: IC2.9 (PD5), LED_MOTOR_L1.1, MOTOR_CONTROLLER.2 (IN1); also elsewhere on the board
PD6: IC2.10 (PD6), LED_MOTOR_L2.1, MOTOR_CONTROLLER.3 (IN2)
PD7: IC2.11 (PD7); also elsewhere on the board
RESET: BUTTON_RESET.P$1 (4), BUTTON_RESET.P$3 (3), C7.2, D3.3 (C), IC2.29 (PC6/RESET), R7.1; also elsewhere on the board
SHIELD: R1.1, TVS1.3, USB_CONN.SHIELD
USB_VCC: C5.1, D2.2 (A), F1.2A (2), F1.2B (2); also elsewhere on the board
VCC: 5VREG.1 (INPUT), C1.1; also elsewhere on the board
VMOT: C8.2, C9.2, C10.2, MOTOR_CONTROLLER.1 (VCC); also elsewhere on the board

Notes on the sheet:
MICRO USB CONN TYPE B RECEP
+5V AUTO SELECTOR

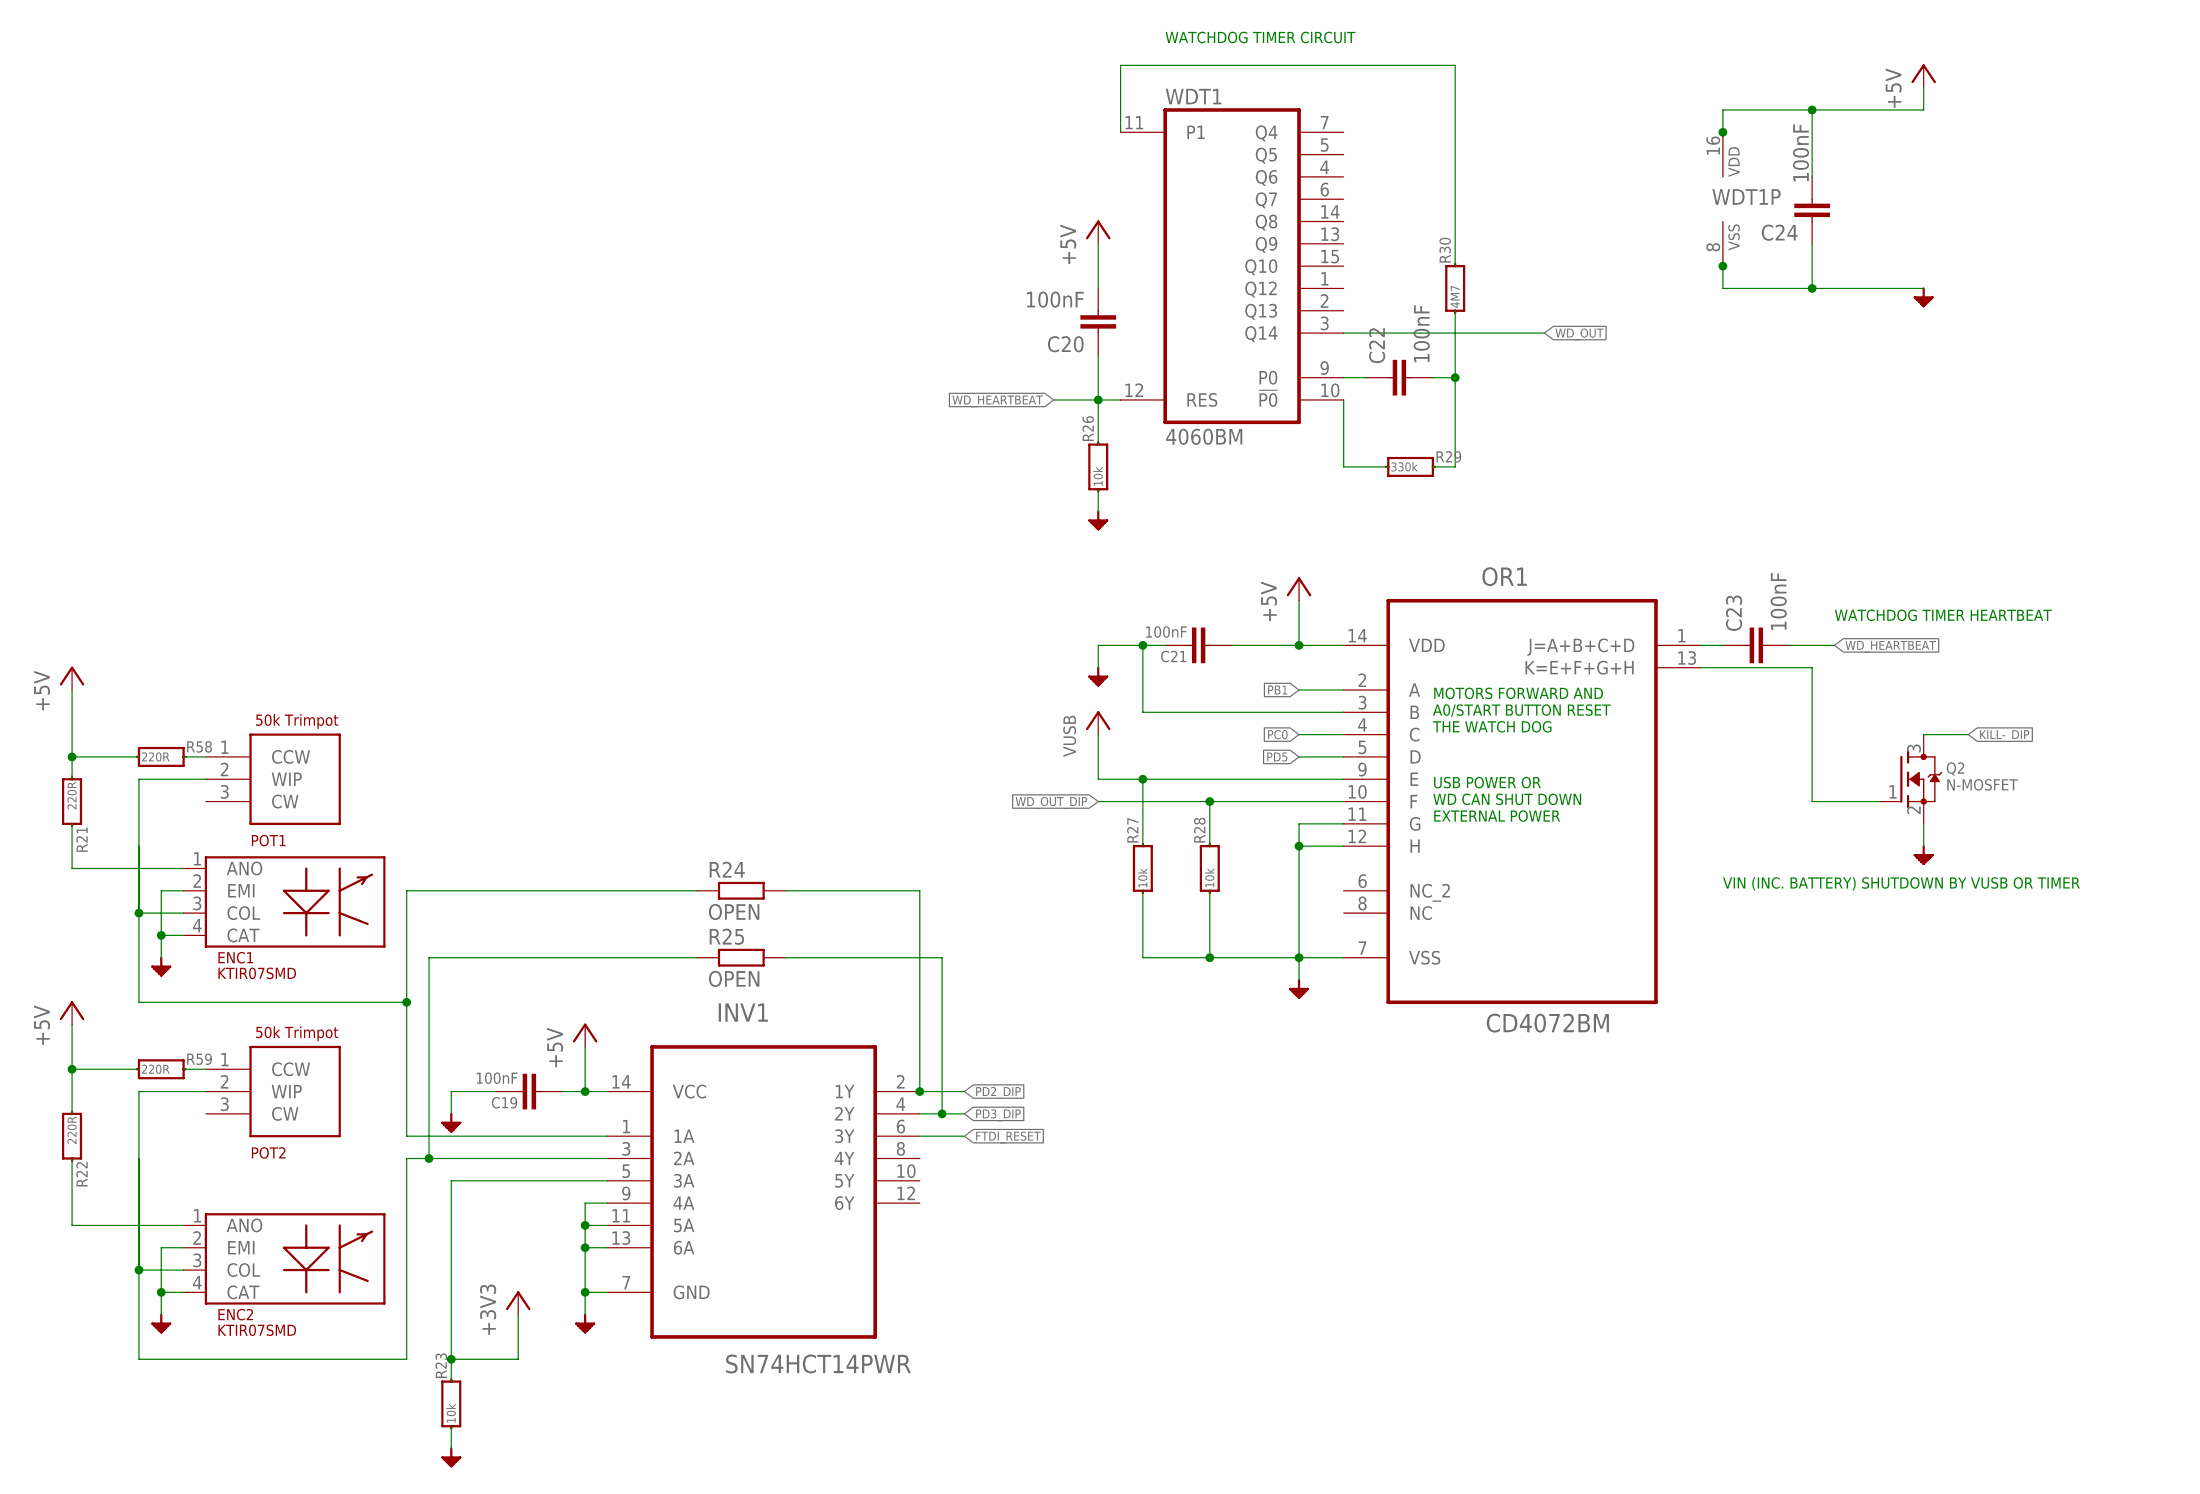
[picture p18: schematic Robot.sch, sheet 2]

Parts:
C19, C20, C21, C22, C23, C24: 100nF; C0805; MPN 08055C104KAT2A
ENC1, ENC2: KTIR07SMD; KTIR07; MPN KTIR0711S
INV1: SN74HCT14PWR; SOP65P640X120-14N; MPN 74HCT14PW,118
OR1: CD4072BM; SOIC127P600X175-14N
POT1, POT2: TC33-TRIMPOT; MPN TC33X-2-503E
Q2: N-MOSFET; SOT23; MPN FDV301N
R21, R22, R58, R59: 220R; R0805; MPN MCWR08X2200FTL
R23, R26, R27, R28: 10k; R0805; MPN RC0805FR-0710KL
R24, R25: OPEN; R0805
R29: 330k; R0805; MPN CRCW0805330KFKEA
R30: 4M7; R0805; MPN RCV08054M70FKEA
WDT1: 4060BM; SO16; MPN CD4060BM

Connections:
+3V3: INV1.5 (3A), R23.2; also elsewhere on the board
+5V: C19.2, C20.2, C21.2, C24.2, INV1.14 (VCC), OR1.14 (VDD), R21.1, R22.1, R58.1, R59.1, WDT1.16 (VDD); also elsewhere on the board
FTDI_RESET: INV1.6 (3Y); also elsewhere on the board
GND: C19.1, C21.1, C24.1, ENC1.2 (EMI), ENC1.4 (CAT), ENC2.2 (EMI), ENC2.4 (CAT), INV1.7 (GND), INV1.9 (4A), INV1.11 (5A), INV1.13 (6A), OR1.3 (B), OR1.7 (VSS), OR1.11 (G), OR1.12 (H), Q2.2 (S), R23.1, R26.1, R27.1, R28.1, WDT1.8 (VSS); also elsewhere on the board
KILL-_DIP: Q2.3 (D); also elsewhere on the board
unnamed: C23.1, OR1.1 (J=A+B+C+D)
unnamed: ENC1.1 (ANO), R21.2
unnamed: ENC2.1 (ANO), R22.2
unnamed: ENC2.3 (COL), INV1.3 (2A), POT2.2 (WIP), R25.1
unnamed: R29.1, WDT1.10 (!P0)
unnamed: ENC1.3 (COL), INV1.1 (1A), POT1.2 (WIP), R24.1
unnamed: C22.1, WDT1.9 (P0)
unnamed: POT2.1 (CCW), R59.2
unnamed: R30.2, WDT1.11 (P1)
unnamed: POT1.1 (CCW), R58.2
unnamed: C22.2, R29.2, R30.1
PB1: OR1.2 (A); also elsewhere on the board
PC0: OR1.4 (C); also elsewhere on the board
PD2_DIP: INV1.2 (1Y), R24.2; also elsewhere on the board
PD3_DIP: INV1.4 (2Y), R25.2; also elsewhere on the board
PD5: OR1.5 (D); also elsewhere on the board
USB/WD_KILL-: OR1.13 (K=E+F+G+H), Q2.1 (G)
USB_VCC: OR1.9 (E), R27.2; also elsewhere on the board
WD_HEARTBEAT: C20.1, C23.2, R26.2, WDT1.12 (RES)
WD_OUT: WDT1.3 (Q14); also elsewhere on the board
WD_OUT_DIP: OR1.10 (F), R28.2; also elsewhere on the board

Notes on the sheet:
WATCHDOG TIMER CIRCUIT
WATCHDOG TIMER HEARTBEAT
VIN (INC. BATTERY) SHUTDOWN BY VUSB OR TIMER
MOTORS FORWARD AND A0/START BUTTON RESET THE WATCH DOG
USB POWER OR WD CAN SHUT DOWN EXTERNAL POWER

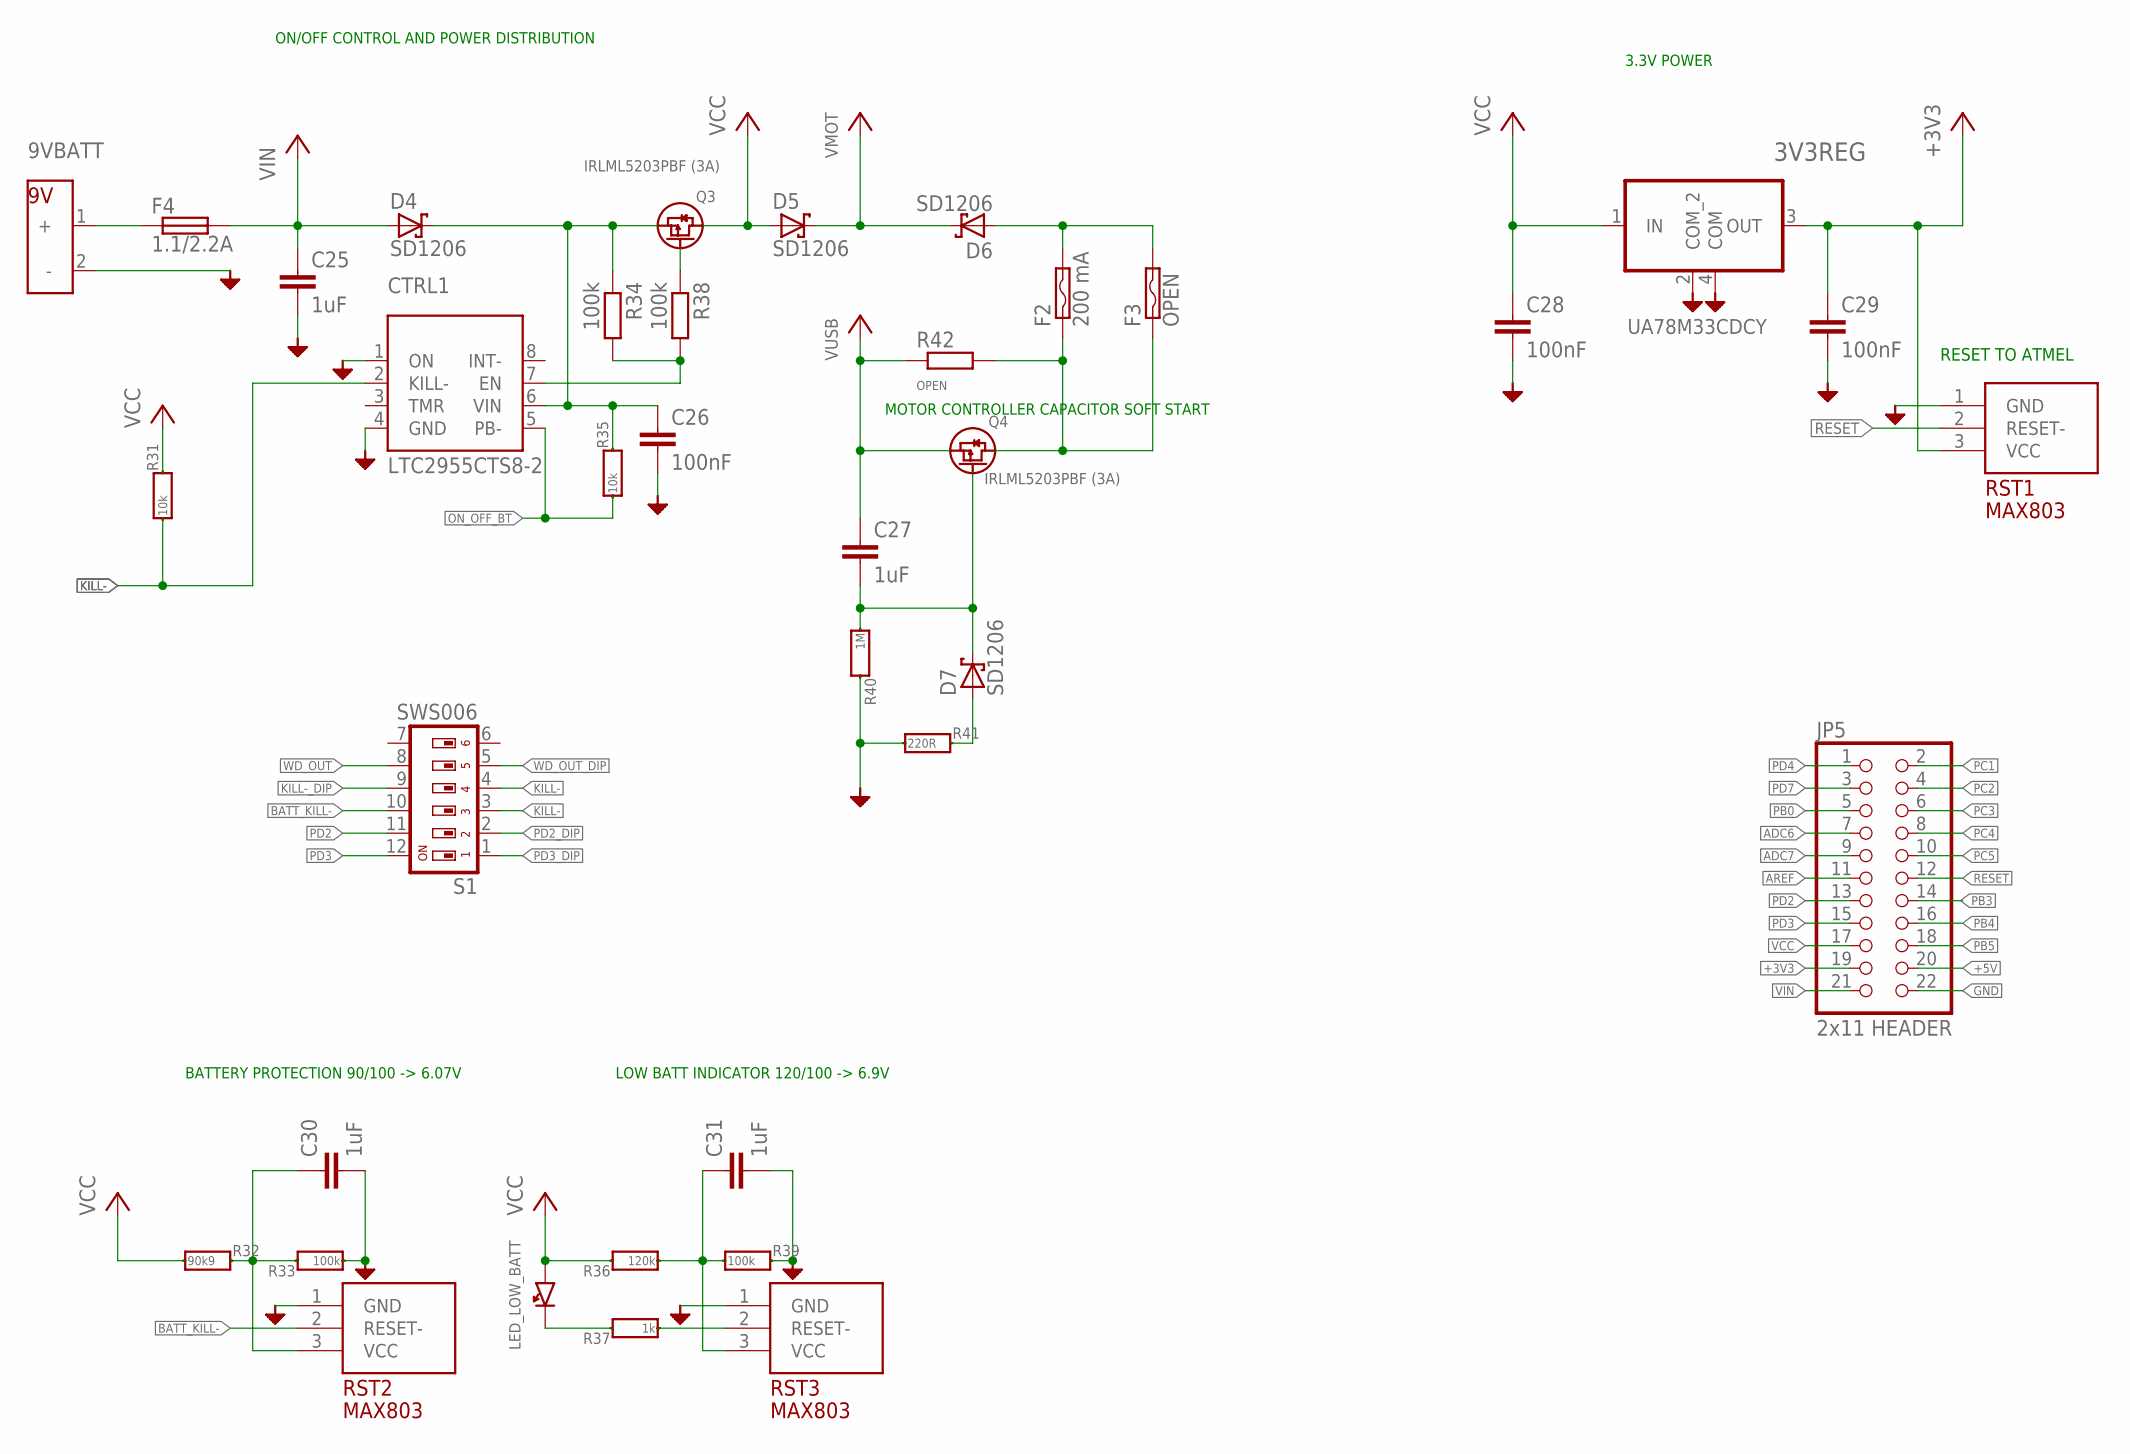
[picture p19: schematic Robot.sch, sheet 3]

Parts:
3V3REG: UA78M33CDCY; SOT230P700X180-4N
9VBATT: BATTERY_9V; BATTERY_PAC; MPN 967
C25, C27, C30, C31: 1uF; C0805; MPN 0805B104K500CT
C26, C28, C29: 100nF; C0805; MPN 08055C104KAT2A
CTRL1: LTC2955CTS8-2; 8TSOT23; MPN LTC2955CTS8-2#TRMPBF
D4, D5, D6, D7: SD1206; MPN SD1206S040S2R0
F2: 200 mA; PT1206; MPN NANOSMDC020F-2
F3: OPEN; PT1206
F4: 1.1/2.2A; C1812; MPN MINISMDC110F/16-2; FARNELL 2473642
JP5: 2x11 HEADER; 2X11; MPN 2214S-22SG-85
LED_LOW_BATT: KPC-3216EC (RED); LED3216_PAC; MPN KPC-3216EC
Q3, Q4: IRLML5203PBF (3A); SOT23; MPN IRLML5203PBF
R31, R35: 10k; R0805; MPN RC0805FR-0710KL
R32: 90k9; R0805; MPN MC01W0805190K9
R33, R34, R38, R39: 100k; R0805; MPN RC0805FR-07100KL
R36: 120k; R0805; MPN RC0805FR-07120KL
R37: 1k; R0805; MPN CRCW08051K00FKTA
R40: 1M; R0805; MPN CRCW08051M00FKTB
R41: 220R; R0805; MPN MCWR08X2200FTL
R42: OPEN; R0603
RST1, RST2, RST3: MAX803SC; SC70-3L; MPN MAX803SQ293T1G
S1: SWS006; SMS-006; MPN MCDM(R)-06-T

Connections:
+3V3: 3V3REG.3 (OUT), C29.1, JP5.19, RST1.3 (VCC); also elsewhere on the board
+5V: JP5.20; also elsewhere on the board
ADC6: JP5.7; also elsewhere on the board
ADC7: JP5.9; also elsewhere on the board
AREF: JP5.11; also elsewhere on the board
BATT_KILL-: RST2.2 (RESET-), S1.10
BATT_PROT_ADJ: C30.1, R32.2, R33.2, RST2.3 (VCC)
GND: 3V3REG.2 (COM_2), 3V3REG.4 (COM), 9VBATT.2 (-), C25.2, C26.2, C28.2, C29.2, C30.2, C31.2, CTRL1.1 (ON), CTRL1.4 (GND), JP5.22, R33.1, R39.2, R40.2, R41.1, RST1.1 (GND), RST2.1 (GND), RST3.1 (GND); also elsewhere on the board
KILL-: CTRL1.2 (KILL-), R31.1, S1.3, S1.4
KILL-_DIP: S1.9; also elsewhere on the board
unnamed: Q3.1 (G), R38.1
unnamed: CTRL1.7 (EN), R34.2, R38.2
unnamed: LED_LOW_BATT.2, R37.2
unnamed: D6.ANODE (A), F2.2A (2), F2.2B (2), F3.2A (2), F3.2B (2)
unnamed: R37.1, RST3.2 (RESET-)
unnamed: F2.1A (1), F2.1B (1), F3.1A (1), F3.1B (1), Q4.3 (D), R42.2
unnamed: C27.2, D7.CATHODE (C), Q4.1 (G), R40.1
unnamed: C26.1, CTRL1.6 (VIN), D4.CATHODE (C), Q3.2 (S), R34.1, R35.2
unnamed: D7.ANODE (A), R41.2
unnamed: 9VBATT.1 (+), F4.2
unnamed: C31.1, R36.1, R39.1, RST3.3 (VCC)
ON_OFF_BT: CTRL1.5 (PB-), R35.1; also elsewhere on the board
PB0: JP5.5; also elsewhere on the board
PB3: JP5.14; also elsewhere on the board
PB4: JP5.16; also elsewhere on the board
PB5: JP5.18; also elsewhere on the board
PC1: JP5.2; also elsewhere on the board
PC2: JP5.4; also elsewhere on the board
PC3: JP5.6; also elsewhere on the board
PC4: JP5.8; also elsewhere on the board
PC5: JP5.10; also elsewhere on the board
PD2: JP5.13, S1.11; also elsewhere on the board
PD2_DIP: S1.2; also elsewhere on the board
PD3: JP5.15, S1.12; also elsewhere on the board
PD3_DIP: S1.1; also elsewhere on the board
PD4: JP5.1; also elsewhere on the board
PD7: JP5.3; also elsewhere on the board
RESET: JP5.12, RST1.2 (RESET-); also elsewhere on the board
USB_VCC: C27.1, Q4.2 (S), R42.1; also elsewhere on the board
VCC: 3V3REG.1 (IN), C28.1, D5.ANODE (A), JP5.17, LED_LOW_BATT.1, Q3.3 (D), R31.2, R32.1, R36.2; also elsewhere on the board
VIN: C25.1, D4.ANODE (A), F4.1, JP5.21
VMOT: D5.CATHODE (C), D6.CATHODE (C); also elsewhere on the board
WD_OUT: S1.8; also elsewhere on the board
WD_OUT_DIP: S1.5; also elsewhere on the board

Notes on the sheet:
RESET TO ATMEL
LOW BATT INDICATOR 120/100 -> 6.9V
BATTERY PROTECTION 90/100 -> 6.07V
3.3V POWER
ON/OFF CONTROL AND POWER DISTRIBUTION
MOTOR CONTROLLER CAPACITOR SOFT START

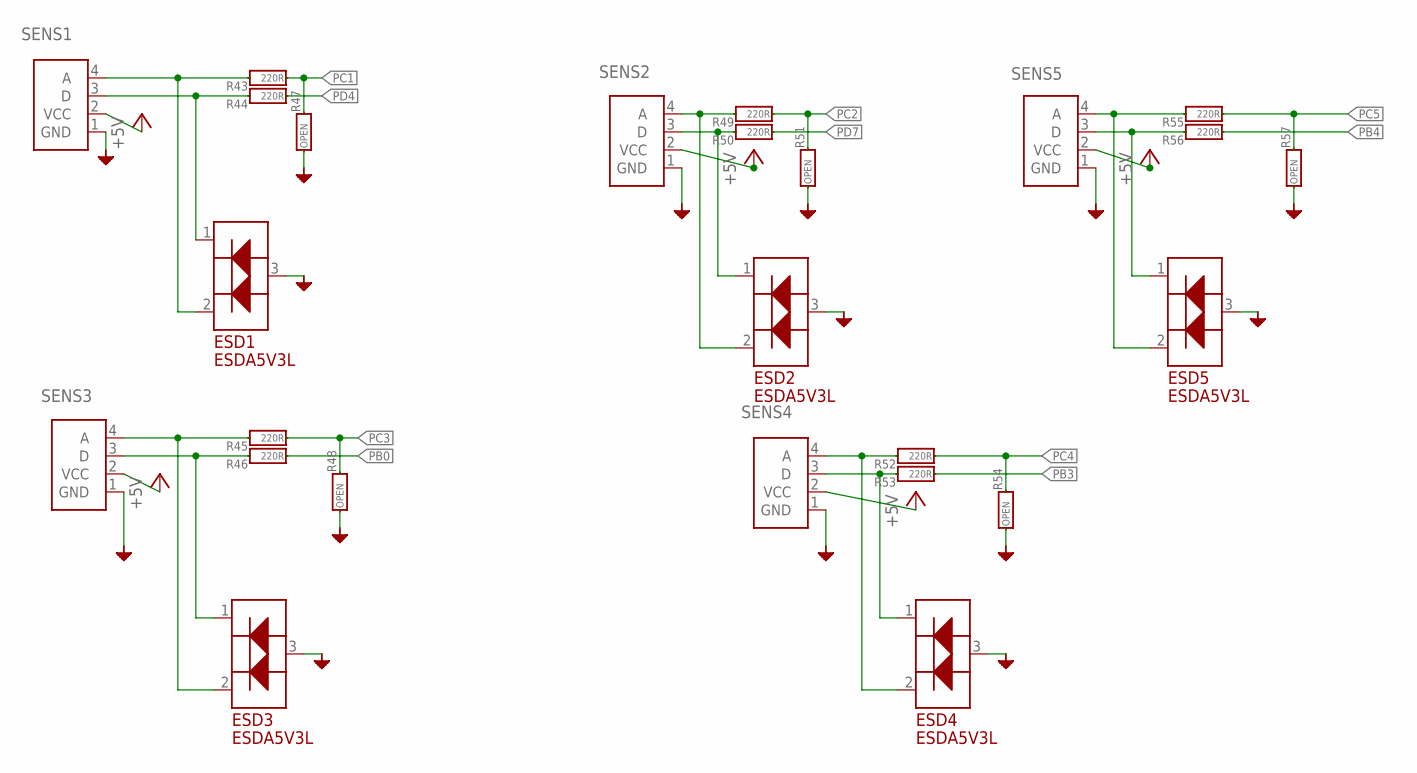
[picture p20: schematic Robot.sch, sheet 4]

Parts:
ESD1, ESD2, ESD3, ESD4, ESD5: ESDA5V3L; SOT23; MPN ESDA5V3L
R43, R44, R45, R46, R49, R50, R52, R53, R55, R56: 220R; R0805; MPN MCWR08X2200FTL
R47, R48, R51, R54, R57: OPEN; R0805
SENS1, SENS2, SENS3, SENS4, SENS5: ROBOT_SENSOR

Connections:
+5V: SENS1.2 (VCC), SENS2.2 (VCC), SENS3.2 (VCC), SENS4.2 (VCC), SENS5.2 (VCC); also elsewhere on the board
GND: ESD1.3, ESD2.3, ESD3.3, ESD4.3, ESD5.3, R47.1, R48.1, R51.1, R54.1, R57.1, SENS1.1 (GND), SENS2.1 (GND), SENS3.1 (GND), SENS4.1 (GND), SENS5.1 (GND); also elsewhere on the board
unnamed: ESD4.2, R52.2, SENS4.4 (A)
unnamed: ESD4.1, R53.2, SENS4.3 (D)
unnamed: ESD3.2, R45.2, SENS3.4 (A)
unnamed: ESD1.2, R43.2, SENS1.4 (A)
unnamed: ESD5.2, R55.2, SENS5.4 (A)
unnamed: ESD5.1, R56.2, SENS5.3 (D)
unnamed: ESD2.2, R49.2, SENS2.4 (A)
unnamed: ESD2.1, R50.2, SENS2.3 (D)
unnamed: ESD1.1, R44.2, SENS1.3 (D)
unnamed: ESD3.1, R46.2, SENS3.3 (D)
PB0: R46.1; also elsewhere on the board
PB3: R53.1; also elsewhere on the board
PB4: R56.1; also elsewhere on the board
PC1: R43.1, R47.2; also elsewhere on the board
PC2: R49.1, R51.2; also elsewhere on the board
PC3: R45.1, R48.2; also elsewhere on the board
PC4: R52.1, R54.2; also elsewhere on the board
PC5: R55.1, R57.2; also elsewhere on the board
PD4: R44.1; also elsewhere on the board
PD7: R50.1; also elsewhere on the board

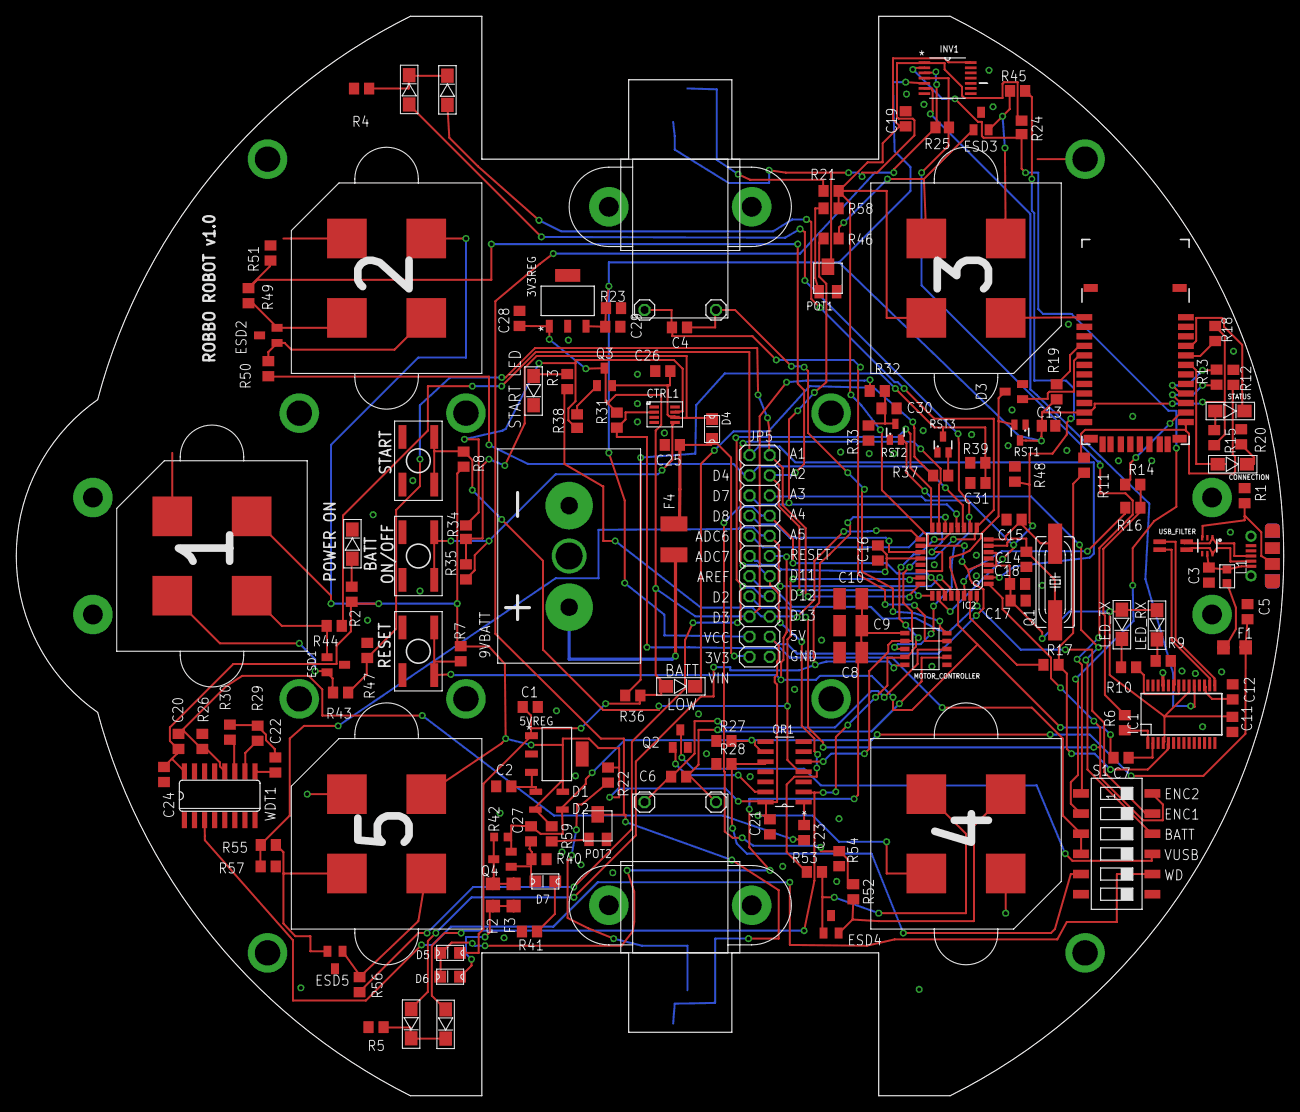
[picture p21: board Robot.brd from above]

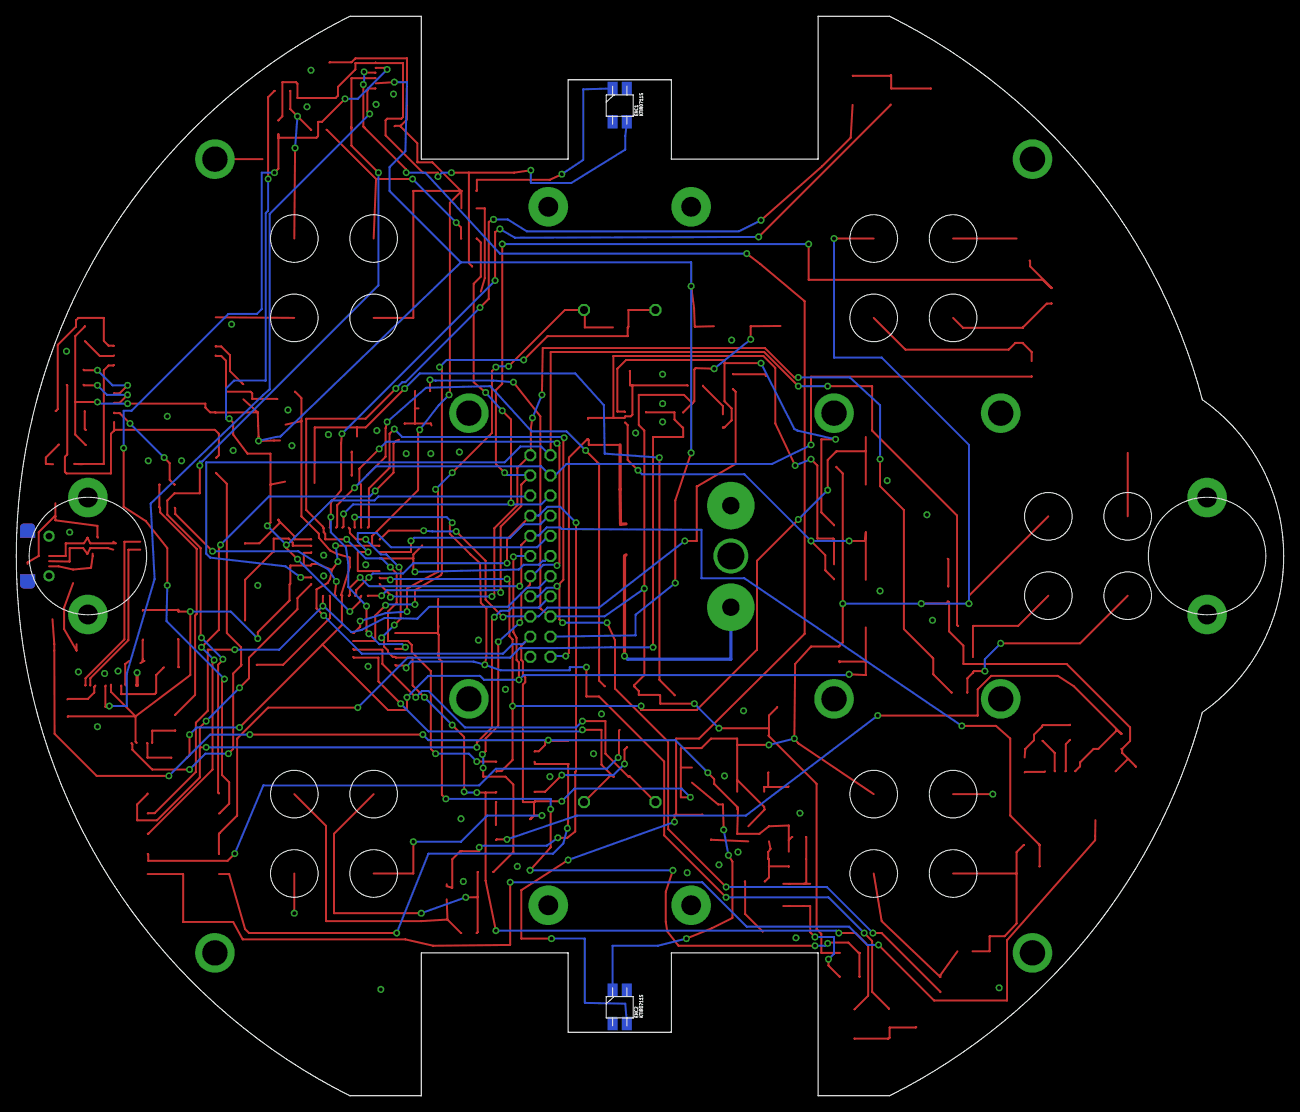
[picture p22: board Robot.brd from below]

Board: 2 copper layers, 159.7 x 136.0 mm, 159 parts (2 on the bottom side), 113 nets.

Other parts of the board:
U$3, U$4: MOTOR_HOLDER

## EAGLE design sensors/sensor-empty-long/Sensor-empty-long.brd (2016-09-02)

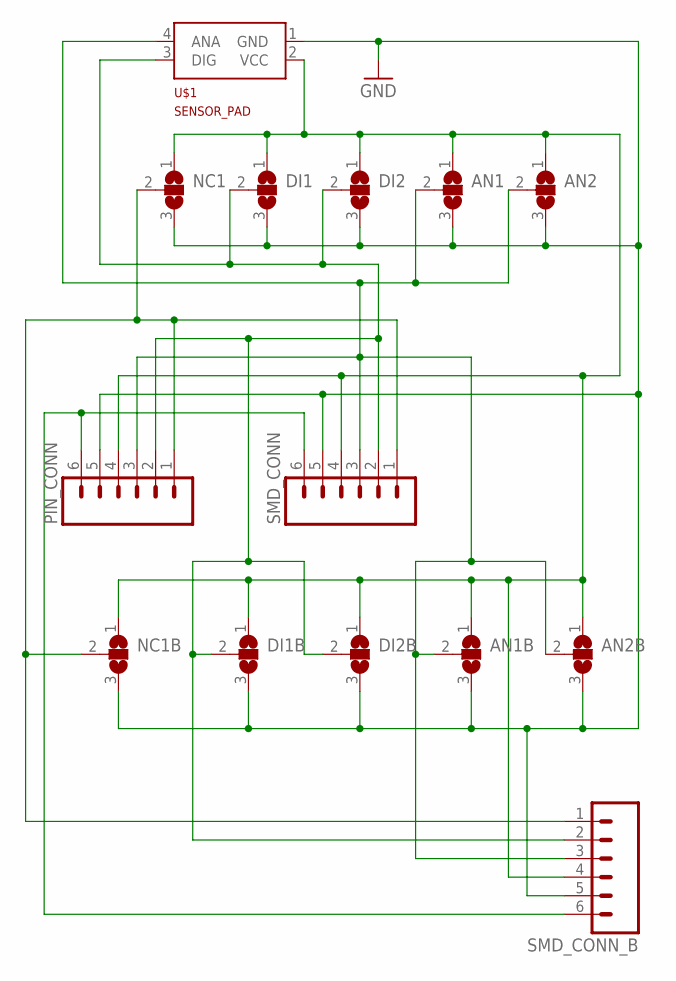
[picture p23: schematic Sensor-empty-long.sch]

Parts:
AN1, AN1B, AN2, AN2B: SJ2W; SJ_2
DI1, DI1B, DI2, DI2B: SJ2W; SJ_2
NC1, NC1B: SJ2W; SJ_2
PIN_CONN: M06SILK_FEMALE_PTH; 1X06
SMD_CONN: M06SMD-STRAIGHT-COMBO-FEMALE; 1X06_SMD_STRAIGHT_COMBO; MPN BG306-06-A-1-0400-L-B
SMD_CONN_B: M06SMD-STRAIGHT-COMBO-FEMALE; 1X06_SMD_STRAIGHT_COMBO; MPN BG306-06-A-1-0400-L-B
U$1: SENSOR_PAD

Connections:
GND: AN1.3, AN1B.3, AN2.3, AN2B.3, DI1.3, DI1B.3, DI2.3, DI2B.3, NC1.3, NC1B.3, PIN_CONN.5, SMD_CONN.5, SMD_CONN_B.5, U$1.1 (GND)
unnamed: AN1.2, AN1B.2, AN2.2, AN2B.2, PIN_CONN.3, SMD_CONN.3, SMD_CONN_B.3, U$1.4 (ANA)
unnamed: NC1.2, NC1B.2, PIN_CONN.1, SMD_CONN.1, SMD_CONN_B.1
unnamed: AN1.1, AN1B.1, AN2.1, AN2B.1, DI1.1, DI1B.1, DI2.1, DI2B.1, NC1.1, NC1B.1, PIN_CONN.4, SMD_CONN.4, SMD_CONN_B.4, U$1.2 (VCC)
unnamed: PIN_CONN.6, SMD_CONN.6, SMD_CONN_B.6
unnamed: DI1.2, DI1B.2, DI2.2, DI2B.2, PIN_CONN.2, SMD_CONN.2, SMD_CONN_B.2, U$1.3 (DIG)

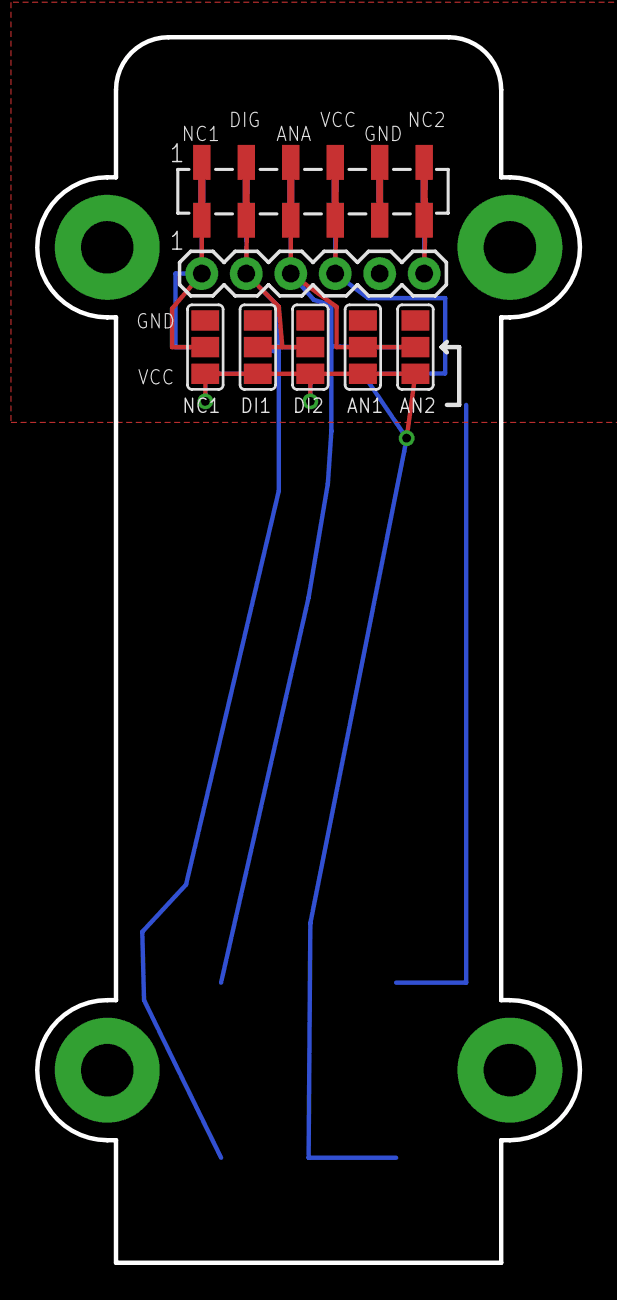
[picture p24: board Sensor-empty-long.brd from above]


Board: 2 copper layers, 31.0 x 70.0 mm, 14 parts (6 on the bottom side), 6 nets.

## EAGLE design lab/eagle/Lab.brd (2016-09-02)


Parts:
BUTTON1, BUTTON2, BUTTON3, BUTTON4, BUTTON5: KSC921J; TACT_SWITCH_4_PIN; MPN KSC921J LFS
C1: 330nF; C0805; MPN 08053C334KAT2A
C2, C5, C6, C7, C8, C10, C12, C15: 100nF; C0805; MPN 08055C104KAT2A
C3: 10nF; C0805; MPN MC0805B103K500CT
C4, C14: 4.7uF; C0805; MPN 0805X475K250CT
C9, C11: 22pF; C0805; MPN CC0805JRNPO9BN220
C13: 470nF; C0805; MPN MC0805F474Z250CT
D1, D2, D7: MBR0520; SOD123; MPN MBR0520L
D3: 5.1V; SOD-323; MPN MM3Z5V1T1G
F1: 500 mA; PT1206; MPN NANOSMDC050F/13.2-2
IC1: FT232RL; SSOP28; MPN FT232RL-REEL
IC2: 74HC164D; SO14; MPN 74HC164D
IC3: ATMEGA328AU/TQFP; TQFP32-08; MPN ATMEGA328P-AU
L1: 600ohm/100Mhz; R0603; MPN 742792651
LED1: KPC-3216SGC (GREEN); LED3216_PAC; MPN KPC-3216SGC
LED2: KPC-3216YC (YELLOW); LED3216_PAC; MPN KPC-3216YC
LED3, LED4, LED5, LED6, LED7, LED8, LED9, LED10, LED11: KPC-3216EC (RED); LED3216_PAC; MPN KPC-3216EC
LED_RX: KPC-3216EC (RED); LED3216_PAC; MPN KPC-3216EC
LED_TX: KPC-3216SGC (GREEN); LED3216_PAC; MPN KPC-3216SGC
MIC1: ABM-707-RC; MPN ABM-707-RC
P1, P4: TSM-108-02-L-SV; FE08; MPN 2212S-08SG-85
P2: TSM-106-02-L-SV; FE06; MPN 2212S-06SG-85
P3: TSM-110-02-L-SV; FE10; MPN 2212S-10SG-85
PHOTOTRANSISTOR: SFH3410SMD; SFH3410; MPN SFH3410-Z
POWER: KPC-3216SGC (GREEN); LED3216_PAC; MPN KPC-3216SGC
Q1: LFXTAL003237; SM49; MPN LFXTAL003237
Q2: BC850; MY_SOT23; MPN BC850C,215
R1: 0R; R0805; MPN MC01W08050R
R2, R3, R4, R7, R8, R9, R10, R11, R12, R13, R14, R15, R16, R17, R18, R19, R20, R21, R22, R30, R31, R37, R38: 1k; R0805; MPN CRCW08051K00FKTA
R5, R6, R23, R24, R25, R26, R29, R32, R40: 10k; R0805; MPN RC0805FR-0710KL
R27: 2k2; R0805; MPN RC0805FR-072K2L.
R28: 100k; R0805; MPN RC0805FR-07100KL
RESET_BUTTON: KSC921J; TACT_SWITCH_4_PIN; MPN KSC921J LFS
SLIDER_RESISTOR: PTA4543; MPN PTA4543-2015DPB103
SPEAKER: MCABT-458-RC; SMD_SPK_PAC; MPN MCABT-458-RC
U1: UA78M05CDCY; SOT230P700X180-4N
U$1: USB-CON-5PIN; USB-MICRO-MOLEX-105017-0001_V2; MPN 105017-0001
U$2: PRTR5V0U4Y; SOT363; MPN PRTR5V0U4Y,125
U$3, U$4, U$5, U$6: FIDUCIAL; FIDUCIAL_1MM
USB_FILTER: SRF3216A; MPN SRF3216A-900Y

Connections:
+3V3: C8.1, IC1.17 (3.3VOUT), P1.5
+5V: C7.2, C12.2, C14.2, C15.2, D1.1 (K), D7.1 (K), IC1.4 (VCCIO), IC1.20 (VCC), IC2.14 (VCC), IC3.4 (VCC1), IC3.6 (VCC2), IC3.18 (AVCC), LED_RX.1, LED_TX.1, P1.4, P1.7, PHOTOTRANSISTOR.COLLECTOR, R2.1, R3.2, R4.2, R8.2, R9.2, R10.2, R26.2, R27.2, R29.2, SLIDER_RESISTOR.1; also elsewhere on the board
ADC6: IC3.19 (ADC6)
ADC7: IC3.22 (ADC7), SLIDER_RESISTOR.2
AREF: C10.2, IC3.20 (AREF), P3.8
CLK: IC2.8 (CLK); also elsewhere on the board
DATA: IC2.1 (A), IC2.2 (B); also elsewhere on the board
FTDI_RESET: IC1.19 (RESET); also elsewhere on the board
GND: C1.2, C2.2, C3.1, C4.2, C5.2, C7.1, C8.2, C9.2, C10.1, C11.2, C12.1, C14.1, C15.1, D3.A, IC1.7 (GND1), IC1.18 (GND2), IC1.21 (GND3), IC1.25 (AGND), IC1.26 (TEST), IC2.7 (GND), IC3.3 (GND1), IC3.5 (GND2), IC3.21 (GND3), LED1.2, LED2.2, LED3.2, LED4.2, LED5.2, LED6.2, LED7.2, LED8.2, LED9.2, LED10.2, LED11.2, MIC1.GND (2), P1.2, P1.3, P3.7, POWER.2, Q2.2, R1.2, R5.1, R6.1, R23.1, R24.1, R25.1, R32.1, R40.2, RESET_BUTTON.P$2 (2), RESET_BUTTON.P$4 (1), SLIDER_RESISTOR.3, SPEAKER.2, U1.2 (COMMON_2), U1.4 (COMMON), U$1.5 (GND), U$2.2; also elsewhere on the board
LIGHT: PHOTOTRANSISTOR.EMITTER, R32.2; also elsewhere on the board
MIC: Q2.3, R28.2, R29.1; also elsewhere on the board
unnamed: C11.1, IC3.8 (PB7/XTAL2), Q1.2
unnamed: C9.1, IC3.7 (PB6/XTAL1), Q1.1
unnamed: LED5.1, R16.2
unnamed: LED3.1, R14.2
unnamed: LED2.1, R13.2
unnamed: LED1.1, R12.2
unnamed: LED4.1, R15.2
unnamed: LED6.1, R17.2
unnamed: LED7.1, R18.2
unnamed: LED8.1, R19.2
unnamed: LED9.1, R20.2
unnamed: D2.2 (A), P1.1
unnamed: LED10.1, R21.2
unnamed: IC1.23 (CBUS0), R7.1
unnamed: C6.1, IC1.2 (DTR)
unnamed: POWER.1, R2.2
unnamed: IC1.15 (USBDB), USB_FILTER.2
unnamed: IC1.16 (USBDM), USB_FILTER.3
unnamed: LED11.1, R22.2
unnamed: IC3.30 (PD0/RXD), R30.1
unnamed: IC2.3 (QA), R15.1
unnamed: IC2.4 (QB), R16.1
unnamed: IC2.5 (QC), R17.1
unnamed: LED_RX.2, R7.2
unnamed: LED_TX.2, R11.2
unnamed: IC1.22 (CBUS1), R11.1
unnamed: U$1.3 (D+), U$2.1, USB_FILTER.1
unnamed: IC3.31 (PD1/TXD), R31.1
unnamed: BUTTON1.P$2 (2), BUTTON1.P$4 (1), R3.1
unnamed: BUTTON2.P$2 (2), BUTTON2.P$4 (1), R4.1
unnamed: U$1.2 (D-), U$2.6, USB_FILTER.4
unnamed: BUTTON4.P$2 (2), BUTTON4.P$4 (1), R9.1
unnamed: BUTTON5.P$2 (2), BUTTON5.P$4 (1), R10.1
unnamed: BUTTON3.P$2 (2), BUTTON3.P$4 (1), R8.1
unnamed: F1.1A (1), F1.1B (1), L1.1
unnamed: IC1.5 (RXD), R38.2
unnamed: IC1.1 (TXD), R37.2
unnamed: C2.1, D7.2 (A), U1.3 (OUTPUT)
unnamed: IC2.6 (QD), R18.1
unnamed: IC2.10 (QE), R19.1
unnamed: IC2.11 (QF), R20.1
unnamed: IC2.12 (QG), R21.1
unnamed: IC2.13 (QH), R22.1
unnamed: C13.1, Q2.1, R28.1
unnamed: C13.2, MIC1.SIG (1), R27.1
unnamed: C3.2, L1.2, U$1.1 (VBUS), U$2.5
PB0: BUTTON1.P$1 (4), BUTTON1.P$3 (3), IC3.12 (PB0), P3.1, R5.2
PB1: BUTTON2.P$1 (4), BUTTON2.P$3 (3), IC3.13 (PB1), P3.2, R6.2
PB2: BUTTON3.P$1 (4), BUTTON3.P$3 (3), IC3.14 (PB2), P3.3, R23.2
PB3: BUTTON4.P$1 (4), BUTTON4.P$3 (3), IC3.15 (PB3/MOSI), P3.4, R24.2
PB4: BUTTON5.P$1 (4), BUTTON5.P$3 (3), IC3.16 (PB4/MISO), P3.5, R25.2
PB5: IC3.17 (PB5/SCK), P3.6; also elsewhere on the board
PC0: IC3.23 (PC0/ADC0), P2.6; also elsewhere on the board
PC1: IC3.24 (PC1/ADC1), P2.5; also elsewhere on the board
PC2: IC3.25 (PC2/ADC2), P2.4
PC3: IC3.26 (PC3/ADC3), P2.3; also elsewhere on the board
PC4: IC3.27 (PC4/ADC4), P2.2, P3.9; also elsewhere on the board
PC5: IC3.28 (PC5/ADC5), P2.1, P3.10; also elsewhere on the board
PD0/RXD: P4.1, R30.2, R37.1
PD1/TXD: P4.2, R31.2, R38.1
PD2: IC3.32 (PD2), P4.3; also elsewhere on the board
PD3: IC3.1 (PD3), P4.4; also elsewhere on the board
PD4: IC3.2 (PD4), P4.5; also elsewhere on the board
PD5: IC3.9 (PD5), P4.6, R12.1
PD6: IC3.10 (PD6), P4.7, R13.1
PD7: IC3.11 (PD7), P4.8, R14.1
RESET: C6.2, IC3.29 (PC6/RESET), P1.6, R26.1, RESET_BUTTON.P$1 (4), RESET_BUTTON.P$3 (3)
SHIELD1: R1.1, U$1.SHIELD, U$2.3
SPEAKER: D3.C, SPEAKER.1; also elsewhere on the board
SR_#CLR: IC2.9 (CLR), R40.1; also elsewhere on the board
USB_VCC: C4.1, C5.1, D1.2 (A), F1.2A (2), F1.2B (2)
VIN: C1.1, D2.1 (K), U1.1 (INPUT)

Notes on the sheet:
SLIDER POTENTIOMETER
+5V AUTO SELECTOR
+5V REG
ARDUINO SHIELD PINS
MICRO USB CONN TYPE B RECEP


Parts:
A0_CONN, A1_CONN: FC68125; MPN FC68125
C16, C17: 100nF; C0805; MPN 08055C104KAT2A
D0_CONN: FC68125; MPN FC68125
D4, D5, D6: 5.1V; SOD-323; MPN MM3Z5V1T1G
F2: 200 mA; PT1206; MPN NANOSMDC020F-2
IC4, IC5: 74FST3257; SO16; MPN 74FST3257DR2G
R33: 100k; R0805; MPN RC0805FR-07100KL
R34, R35, R36: 220R; M0805; MPN MCWR08X2200FTL
R39: 10k; R0805; MPN RC0805FR-0710KL
S1: 219-02; CTS-219-02; MPN MCEMR-02-T

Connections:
+5V: C16.1, C17.1, F2.2A (2), F2.2B (2), IC4.16 (VCC), IC5.16 (VCC), R39.2, S1.4; also elsewhere on the board
+5V_FUSED: A0_CONN.3_1 (T), A0_CONN.3_2 (T), A1_CONN.3_1 (T), A1_CONN.3_2 (T), D0_CONN.3_1 (T), D0_CONN.3_2 (T), F2.1A (1), F2.1B (1)
CLK: IC5.5 (2B1); also elsewhere on the board
DATA: IC5.2 (1B1); also elsewhere on the board
FTDI_RESET: R39.1, S1.2; also elsewhere on the board
GND: A0_CONN.1 (S), A1_CONN.1 (S), C16.2, C17.2, D0_CONN.1 (S), D4.A, D5.A, D6.A, IC4.8 (GND), IC4.15 (OE-), IC5.8 (GND), IC5.15 (OE-), R33.1, S1.3; also elsewhere on the board
LIGHT: IC4.2 (1B1); also elsewhere on the board
MIC: IC4.5 (2B1); also elsewhere on the board
unnamed: IC4.1 (S), IC5.1 (S), R33.2, S1.1
unnamed: A1_CONN.2 (R), R35.1
unnamed: A0_CONN.2 (R), R34.1
unnamed: D0_CONN.2 (R), R36.1
PB5: D6.C, R36.2; also elsewhere on the board
PC0: D4.C, R34.2; also elsewhere on the board
PC1: D5.C, R35.2; also elsewhere on the board
PC3: IC4.7 (2A); also elsewhere on the board
PC4: IC4.4 (1A); also elsewhere on the board
PC5: IC5.9 (3A); also elsewhere on the board
PD2: IC5.4 (1A); also elsewhere on the board
PD3: IC4.12 (4A); also elsewhere on the board
PD4: IC5.7 (2A); also elsewhere on the board
SPEAKER: IC4.14 (4B1); also elsewhere on the board
SR_#CLR: IC5.11 (3B1); also elsewhere on the board



Board: 2 copper layers, 115.0 x 80.0 mm, 114 parts (2 on the bottom side), 87 nets.

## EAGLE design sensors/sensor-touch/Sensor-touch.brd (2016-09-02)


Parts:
PADS: SENSOR_PAD
R1: 10k; R0805; MPN RC0805FR-0710KL
S1: ESE22; MPN ESE-22MH24

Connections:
GND: PADS.1 (GND), R1.2
unnamed: PADS.4 (ANA), R1.1, S1.P$1 (1)
unnamed: PADS.2 (VCC), S1.P$2 (2)


Board: 2 copper layers, 31.0 x 70.0 mm, 3 parts (0 on the bottom side), 3 nets.

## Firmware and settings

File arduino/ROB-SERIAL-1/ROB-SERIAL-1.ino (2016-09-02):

#include <EEPROM.h>

#define LEFT_MOTOR 9
#define RIGHT_MOTOR 5
#define FORWARD 0
#define BACKWARDS 1

#define SERIAL_ADDRESS 0
#define MOTOR_RATIO_ADDRESS 100
#define SERIAL_LENGTH 20

// EEPROM VARIABLES
// The serial number of the robot, length 50 chars, EEPROM address: 0
char robSerial[SERIAL_LENGTH];// = "000000000000000000000000000000000000000000000000000"; 
// The speed ratio as left / right, EEPROM address: 100  
float motorSpeedRatio = 1;

// MOTOR VARIBLES
int leftMotorSpeed = 255;
int rightMotorSpeed = 255;
int isEncodersEnabled = 0;
volatile int rightStepCount = 0;
volatile int leftStepCount = 0;
// Cumulative time spent on high and low (microseconds) 
volatile long rightTime[2];
volatile long leftTime[2];
// Microsecond time stamps for last two high and low transitions
volatile long rightTimeStamp[2];
volatile long leftTimeStamp[2];
// Last state
volatile bool rightIsHigh;
volatile bool leftIsHigh;

int rightStepLimit = 0;
int leftStepLimit = 0;

int ledOn = 0;

/*
 * Setup the robot.
 */
void setup() {
  Serial.begin(115200);
  while (!Serial) {
    ; // wait for serial port to connect. Needed for native USB port only
  }
  // INPUTS
  pinMode(2, INPUT);
  pinMode(3, INPUT);
  // OUTPUTS
  pinMode(5, OUTPUT);
  pinMode(6, OUTPUT);
  pinMode(9, OUTPUT);
  pinMode(10, OUTPUT);
  pinMode(13, OUTPUT);

  /*
  Serial.println("");
  Serial.println("ANNA SARJANUMERO");
  while(!Serial.available()) {
   // wait
  }
  String s = Serial.readStringUntil('\n');
  s.toCharArray(robSerial, SERIAL_LENGTH);
  */

  /*
  // SET EEPROM VARIABLES
  //robSerialIN[] = "ROB-R-1-1-X";
  for (int i = 0 ; i < EEPROM.length() ; i++) {
    EEPROM.write(i, 0);
  }
  EEPROM.put(SERIAL_ADDRESS, robSerial);
  EEPROM.put(MOTOR_RATIO_ADDRESS, 1.0f);
 
  // GET EEPROM VARIABLES
  EEPROM.get(SERIAL_ADDRESS, robSerial);
  EEPROM.get(MOTOR_RATIO_ADDRESS, motorSpeedRatio);
  setMotorSpeeds(255);
  
  // DEBUG EEPROM
  Serial.print("SERIAL: ");
  Serial.println(robSerial);
  Serial.print("MOTOR SPEED RATIO: ");
  Serial.println(motorSpeedRatio, 5);
  
  
  // BLUETOOTH
  setBluetoothName();
  */
  
  // START BUTTON
  while(digitalRead(A0) == HIGH) {
    digitalWrite(13, ledOn = !ledOn);
    delay(500);
  }

  // SET A0 LOW TO ENABLE WD TIMER HEARTBEAT 
  pinMode(A0, OUTPUT);
  digitalWrite(A0, LOW);
}

/*
 * The main loop.
 */
void loop(){
  move7();
}

void move1() {
  for(int i = 0; i < 4; i++) {
    rotateBySteps(90);
    rotateBySteps(-90);
    moveStraightBySteps(FORWARD, 5);
    delay(300);
    rotateBySteps(90);
    delay(300);
  }
}

void move2() {
    moveStraightBySteps(FORWARD, 100);
    delay(1000);
    moveStraightBySteps(BACKWARDS, 100);
    delay(1000);
}

void move3() {
    while(1) {
      moveStraightBySteps(FORWARD, 50);
      //delay(500);
      rotateBySteps(10);
      //delay(500);
    }
}

void move4() {
    while(1) {
      for(int i = 0; i < 20; i++) {
        moveStraightBySteps(FORWARD, 5);
        rotateBySteps(2);
      }
      rotateBySteps(20);
    }
}

void move5() {
    while(1) {
       moveStraightBySteps(FORWARD, 20);
       rotateBySteps(10);
       moveStraightByTime(FORWARD, 200);
       rotateByTime(-200);
    }
}

void move6() {
    while(1) {
       moveStraightByTime(FORWARD, 5000);
       moveStraightByTime(FORWARD, -5000);
    }
}

void move7() {
  while (Serial.available()) {
    char a = Serial.read();
    switch (a) {
      case 'f':
        moveStraightByTime(FORWARD, 500);
        break;
      case 'b':
        moveStraightByTime(BACKWARDS, 500);
        break;
      case 'r':
        rotateByTime(100);
        break;
      case 'l':
        rotateByTime(-100);
        break;
      case 's':
        Serial.print("SERIAL: ");
        Serial.println(robSerial);
        break;
      default:
        Serial.print("UNKNOWN COMMAND: ");
        Serial.println(a);
    }
  }  
}

void move8() {
  enableEncoders(1);
  changeMotorState(RIGHT_MOTOR, 0, 255);
  changeMotorState(LEFT_MOTOR, 0, 255);
  while(1) {
    enableEncoders(1);
    delay(400);
    enableEncoders(0);
    // right
    Serial.print(rightTime[0]);
    Serial.print("/");
    Serial.print(rightTime[1]);
    Serial.print(" ms (");
    Serial.print(rightStepCount * 0.55 / 0.4, 0);
    Serial.print(" cm/s)");
    // left
    Serial.print("\t\t");
    Serial.print(leftTime[0]);
    Serial.print("/");
    Serial.print(leftTime[1]);
    Serial.print(" ms (");
    Serial.print(leftStepCount * 0.55 / 0.4, 0);
    Serial.print(" cm/s)");
    
    Serial.println(); 
  }
}

/*
 * Sets the name of the bluetooth module RN-42 to match the serial numbet of the robot.
 */
void setBluetoothName() {
  // NOTE: max length is 20 chars
  Serial.print("$$$");
  delay(15);
  Serial.print("SN,");
  Serial.println(robSerial);
  delay(15);
  Serial.println("---");
  delay(15);
  // flush BT responses (CMD, AOK, END)
  while(Serial.available()) { 
    Serial.read();
  }
}

/*
 * Sets the name of the bluetooth module RN-42 to match the serial numbet of the robot.
 */
void getBluetoothSettings() {
  String response = "";
  Serial.print("$$$");
  delay(15);
  Serial.println("D");
  delay(15);
  while(Serial.available()) { 
    response.concat(Serial.read());
  }
  Serial.println("---");
  delay(15);
  while(Serial.available()) { 
    Serial.read();
  }
  Serial.println("BT SETTINGS:");
  Serial.println(response);
}

/*
 * Sets the speed of both motors accoring to the motorSpeedRatio.
 */
void setMotorSpeeds(int motorSpeed) {
  motorSpeed = max(min(motorSpeed, 255), 0);
  leftMotorSpeed = motorSpeedRatio >= 1 ? motorSpeed : motorSpeed * motorSpeedRatio;
  rightMotorSpeed = motorSpeedRatio <= 1 ? motorSpeed : motorSpeed / motorSpeedRatio;
}

/*
 * Enables or diasbles encoder interrupts and sets the isEncodersEnabled flag.
 */
void enableEncoders(bool doEnable) {
  if (doEnable) {
    rightStepCount = 0;
    rightTime[0] = 0;
    rightTime[1] = 0;
    rightTimeStamp[0] = 0;
    rightTimeStamp[1] = 0;
    leftStepCount = 0;
    leftTime[0] = 0;
    leftTime[1] = 0;
    leftTimeStamp[0] = 0;
    leftTimeStamp[1] = 0;
    attachInterrupt(digitalPinToInterrupt(2), incRight, CHANGE);
    attachInterrupt(digitalPinToInterrupt(3), incLeft, CHANGE);
    isEncodersEnabled = 1;
  }
  else {
    detachInterrupt(digitalPinToInterrupt(2));
    detachInterrupt(digitalPinToInterrupt(3));
    isEncodersEnabled = 0;
  }
}

/*
 * The interrupt method for the right motor. Increses step count by one.
 */
void incRight() {
  rightStepCount++;
  rightIsHigh = digitalRead(2);
  rightTimeStamp[rightIsHigh] = millis();
  if (rightStepCount > 1)
    rightTime[rightIsHigh] += rightTimeStamp[rightIsHigh] - rightTimeStamp[!rightIsHigh];
}

/*
 * The interrupt method for the left motor. Increses step count by one.
 */
void incLeft() {
  leftStepCount++;
  leftIsHigh = digitalRead(3);
  leftTimeStamp[leftIsHigh] = millis();
  if (leftStepCount > 1)
    leftTime[leftIsHigh] += leftTimeStamp[leftIsHigh] - leftTimeStamp[!leftIsHigh];
}

/*
 * Prints current step counts for both motors.
 */
void printStepCounts() {
  Serial.print(rightStepCount);
  Serial.print(",");
  Serial.println(leftStepCount);
}

/*
 * Prints the state of both encoders (HIGH/LOW) 
 */
void printEnc() {
  Serial.print("ENC: ");
  Serial.print(digitalRead(2));
  Serial.print(",");
  Serial.println(digitalRead(3));
}

/*
 * Brakes both motors by setting full hold power on for 200 ms and then releses the wheels.
 */
void holdAndReleaseBrake() {
  changeMotorState(LEFT_MOTOR, 0, -1);
  changeMotorState(RIGHT_MOTOR, 0, -1);
  // brake for 200 ms
  delay(200);
  // neutral gear
  changeMotorState(LEFT_MOTOR, 0, 0);
  changeMotorState(RIGHT_MOTOR, 0, 0);
}

/*
 * Blocks until the motors have completed the given amount of motion.
 * Brakes briefly.
 */
void waitForMotors(int timeInMs) {
  if (timeInMs > 0)
    delay(timeInMs);
  else {
    while(rightStepCount < rightStepLimit && leftStepCount < leftStepLimit){
      // wait while one of the motors reaches its step limit
    }
  }
  holdAndReleaseBrake();
  //printStepCounts();
}

/*
 * Moves the robot in straight line for a given number of steps (1 step ~ 0,5 cm).
 * Time is in ms, always positive.
 */
void moveStraightBySteps(int motorGear, int steps) {
  if (!isEncodersEnabled)
    enableEncoders(1);
  leftStepLimit = steps;
  rightStepLimit = steps;
  changeMotorState(LEFT_MOTOR, motorGear, leftMotorSpeed);
  changeMotorState(RIGHT_MOTOR, motorGear, rightMotorSpeed);  
  waitForMotors(0);
}

/*
 * Moves the robot in straight line for a given time. Time is in ms, always positive.
 */
void moveStraightByTime(int motorGear, int timeInMs) {
  if (isEncodersEnabled)
    enableEncoders(0);
  changeMotorState(LEFT_MOTOR, motorGear, leftMotorSpeed);
  changeMotorState(RIGHT_MOTOR, motorGear, rightMotorSpeed);  
  waitForMotors(timeInMs);
}

/*
 * Rotates the robot by steps (1 step ~ 5 deg). Positive is to the right, negative to the left.
 */
void rotateBySteps(int steps) {
  if (!isEncodersEnabled)
    enableEncoders(1);
  bool doRotateRight = steps > 0;
  leftStepLimit = abs(steps);
  rightStepLimit = abs(steps);
  changeMotorState(LEFT_MOTOR, !doRotateRight, leftMotorSpeed);
  changeMotorState(RIGHT_MOTOR, doRotateRight, rightMotorSpeed);
  waitForMotors(0);
}

/*
 * Rotates the robot for a given time. Time in ms, positive is to the right, negative to the left.
 */
void rotateByTime(int timeInMs) {
  if (isEncodersEnabled)
    enableEncoders(0);
  bool doRotateRight = timeInMs > 0;
  changeMotorState(LEFT_MOTOR, !doRotateRight, leftMotorSpeed);
  changeMotorState(RIGHT_MOTOR, doRotateRight, rightMotorSpeed);
  waitForMotors(abs(timeInMs));
}

/*
 * The lowest level method to contorl the motors.
 * Side effect: resets the motor's step counter when the motor is started.
 * Parameters:
 * motorSide: 
 *   LEFT / RIGHT (use defined variables)
 * motorGear: 
 *   FORWARD / BACKWARDS (use defined variables)
 * motorSpeed: 
 *   Individual motor speed in PWM (0-255). 
 *   If set to 0, the wheel is free rolling. 
 *   If set to -1, the hold power is on (brake)
 */
void changeMotorState(int motorSide, int motorGear, int motorSpeed) {
  if (motorSide == LEFT_MOTOR) {
    leftStepCount = motorSpeed > 0 ? 0 : leftStepCount;
  }
  if (motorSide == RIGHT_MOTOR) {
    rightStepCount = motorSpeed > 0 ? 0 : rightStepCount;
  }
  if (motorSpeed < 0) {
    // brakes on
    analogWrite(motorSide, 255);
    analogWrite(motorSide + 1, 255);
    return;
  }
  // motorGear = FORWARD   => g1 = 0, g2 = 1
  // motorGear = BACKWARDS => g1 = 1, g2 = 0
  int g1 =  motorGear % 2;
  int g2 = (motorGear + 1) % 2;
  analogWrite(motorSide + g1, 0);
  analogWrite(motorSide + g2, motorSpeed);
}

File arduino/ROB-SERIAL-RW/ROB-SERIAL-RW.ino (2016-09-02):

#include <EEPROM.h>

#define SERIAL_MAX_LENGTH 20

char serialArray[SERIAL_MAX_LENGTH]; // = {0,0,0,0,0,0,0,0,0,0,0,0,0,0,0,0,0,0,0,0};
String serialString = "";

void setup() {
  Serial.begin(115200);  
}

void loop() {
  Serial.println("");
  Serial.println("TYPE IN SERIAL NUMBER AND PRESS ENTER (END WITH NEWLINE CHAR)...");
  Serial.println("");
  while(!Serial.available()) {
   // wait
  }
  serialString = Serial.readStringUntil('\n');
  // WRITE SERIAL
  if (serialString.substring(0,4) == "ROB-" && serialString.length() <= SERIAL_MAX_LENGTH) {
    for (int i = 0 ; i < EEPROM.length() ; i++) {
      EEPROM.write(i, 0);
    }
    for (int i = 0 ; i < serialString.length() ; i++) {
      EEPROM.write(i, serialString[i]);
    }
  }
  // READ SERIAL
  EEPROM.get(0, serialArray);
  Serial.println("CURRENT SERIAL NUMBER IS: ");
  Serial.println(serialArray);
  for(int i = 0; i < SERIAL_MAX_LENGTH; i++) {
    Serial.print(serialArray[i], DEC);
    Serial.print(" ");
  }
  Serial.println();
}

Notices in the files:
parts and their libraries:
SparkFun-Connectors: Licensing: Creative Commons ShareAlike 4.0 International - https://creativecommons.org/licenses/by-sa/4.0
